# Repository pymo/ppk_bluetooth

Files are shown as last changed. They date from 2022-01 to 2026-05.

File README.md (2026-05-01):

# Palm Portable Keyboard Bluetooth Adapter

This project is a DIY Bluetooth module for the Palm Portable Keyboards (PPK), so you can assemble it to your PPK and use it with any host that supports BLE (Bluetooth 4.0 and later).

Where to buy:

I've made some version 3 adapter for sale. Here is the link to the product: [https://www.tindie.com/products/26595/](https://www.tindie.com/products/26595/)

Demo on Youtube:

Bluetooth Palm Portable Keyboard demo (https://www.youtube.com/watch?v=qPznzD5e45k "Version 3 of my Palm Portable Keyboard Bluetooth Adapter (CH582F based)")

This project is inspired by [cy384](https://github.com/cy384/ppk_usb)'s USB PPK adapter, and [Christian](https://hackaday.io/project/181800-palm-pilot-keyboard-bluetooth-conversion)'s ESP32-based PPK bluetooth adapter. 

I've made 3 versions of the adapter: version 1 is based on an Adafruit Feather nRF52840 Express board, version 2 is based on a LilyGo-T-OI-PLUS ESP32-C3 board. version 3 is based on my custom designed CH582F board. Here are the differences of these versions.

| version | Build Tutorial | Highlights | 
| :---: | :---: | :---: |
| Version 1 | [Tutorial](version1_tutorial.md) | Based on an Adafruit Feather nRF52840 Express board. Experimental, no longer supported. Hard to make. Expensive. Micro USB charging. |
| Version 2 | [Tutorial](version2_tutorial.md) | Based on a LilyGo-T-OI-PLUS ESP32-C3 board. Easy to build, cheap, power hungry, no USB HID support. Type-C charging. no longer supported. |
| Version 3 | [Tutorial](version3_tutorial.md) | Based on my custom designed PCB using CH582F chip. Easier to build, cheap, power efficient, USB HID support. Multi-host support. Type-C charging. |

version 3 is the current one I sell in my online store. If you want to DIY and don't want to buy my board, you can choose version 2. version 1 is really old and no longer supported.

- Supported keyboard types
  - Palm III keyboard (p/n P10713U or 3C10317)
  - Palm V keyboard (p/n 3C10439 or Belkin F8E458)
  - Palm M500 keyboard (p/n P10802U or Belkin F8P3501)
  - Handspring Visor (Targus PA800)
  - HP Jornada (Targus PA820)
  - Sony Clie (Targus PA830)
- Unsupported keyboard types
  - connectors for Treo, other PDA/phones, IrDA version.
  - Compaq iPaq PocketPC (Taugus PA840)

Special Key mapping
-----------
- Fn+Tab for Esc
- Fn+number keys for F1-F10, Fn+- for F11, Fn+= for F12
- Fn+up for volume up, Fn+down for volume down
- Fn+left for brightness down, and Fn+right for brightness up.
- Fn+Cmd is Homepage key (Home button in iOS and Android).
- Cmd is mapped to Windows/Apple key.
- Date is mapped to Home, Phone is mapped to End.
- To-Do is mapped to PageUp, Memo is mapped to PageDown.
- Done is mapped to Insert.

Coverage
-----------
Here are some blog posts covering this project:
- [Palm Portable Keyboard Goes Wireless](https://hackaday.com/2022/02/08/palm-portable-keyboard-goes-wireless/) on Hackaday.
- [Upcycling a Palm Portable Keyboard Into a Bluetooth-Enabled Accessory](https://www.hackster.io/news/upcycling-a-palm-portable-keyboard-into-a-bluetooth-enabled-accessory-9ac6c659c1f3) on hackster.io.
- [A Palm Portable Keyboard Bluetooth Adapter](https://www.hackster.io/news/upcycling-a-palm-portable-keyboard-into-a-bluetooth-enabled-accessory-9ac6c659c1f3) on Adafruit blog.

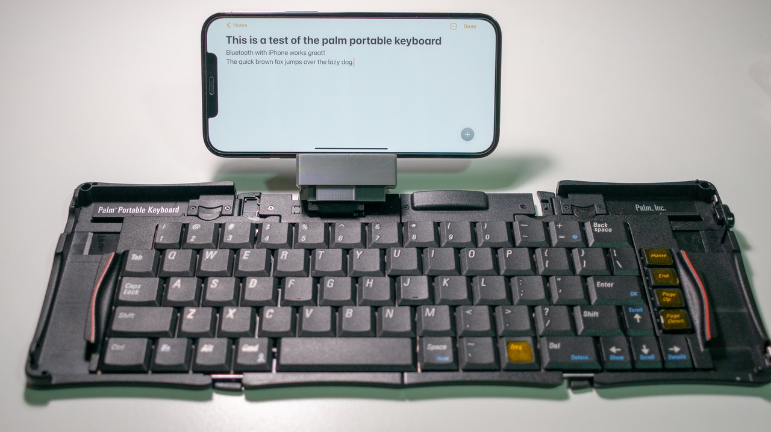
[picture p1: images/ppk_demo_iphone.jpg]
Bluetooth Palm Portable Keyboard's stand supporting an iPhone Bluetooth Palm Portable Keyboard working with a phone


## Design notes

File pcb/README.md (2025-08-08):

# PCB of the version 3 adapter

The version 3 adapter's PCB design and firmware are on [another repository](https://github.com/pymo/wch_micro_kbd), because it is shared with other projects.

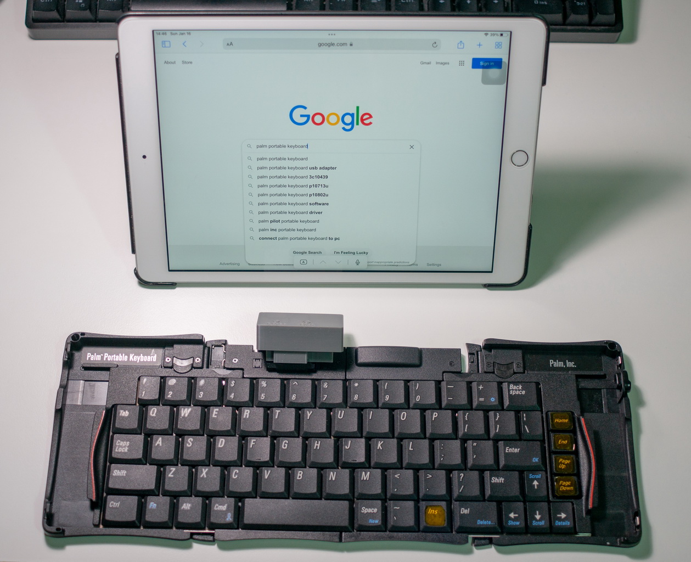
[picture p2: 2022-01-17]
images/ppk_demo.jpg

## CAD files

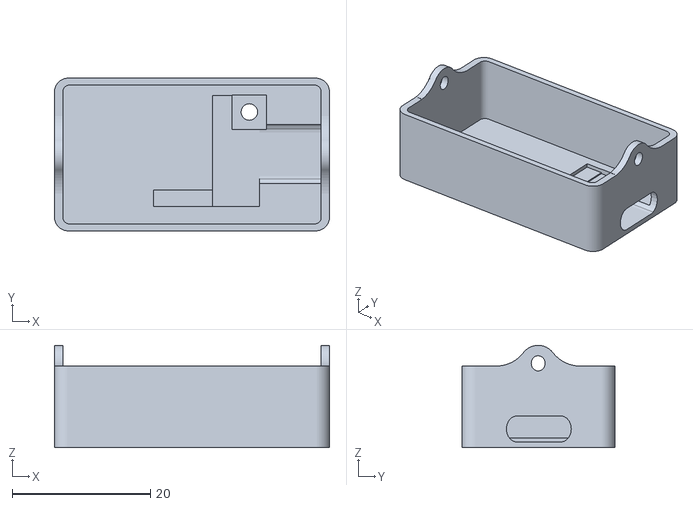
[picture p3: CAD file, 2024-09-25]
3d_print/version3/upper_cap.stl
39.8 x 22.1 x 14.8

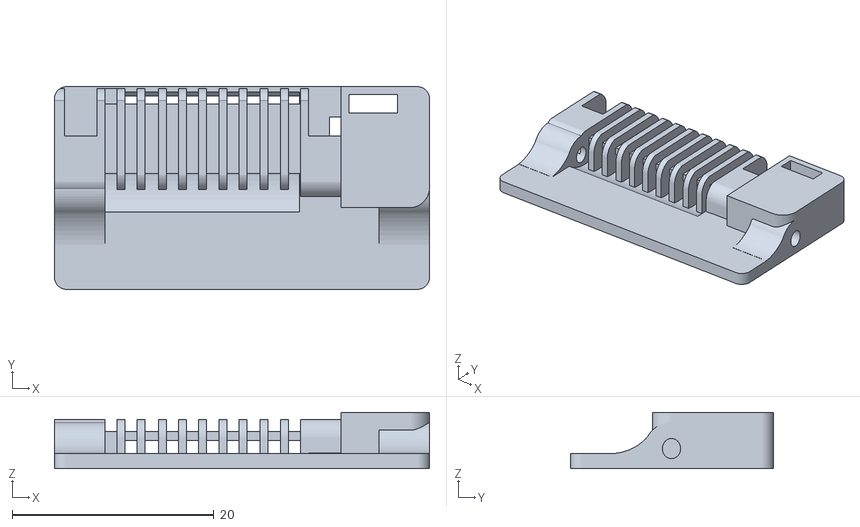
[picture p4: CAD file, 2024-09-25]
3d_print/version3/middle_frame_palm_V.stl
37.2 x 20.1 x 5.60

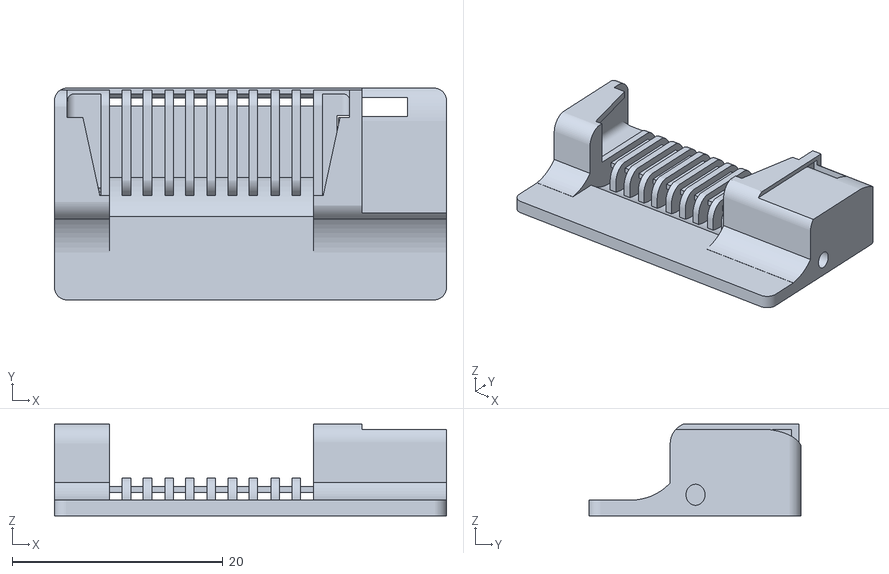
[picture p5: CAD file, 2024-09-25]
3d_print/version3/middle_frame_palm_III.stl
37.2 x 20.1 x 8.70

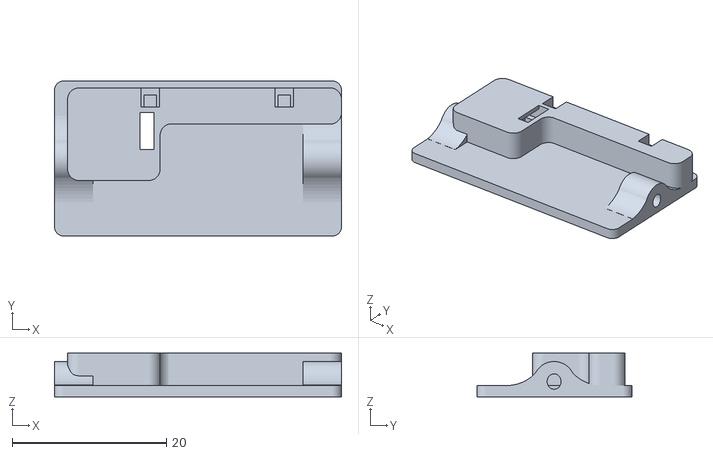
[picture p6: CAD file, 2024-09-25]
3d_print/version3/middle_frame_palm_m500.stl
37.2 x 20.1 x 5.70

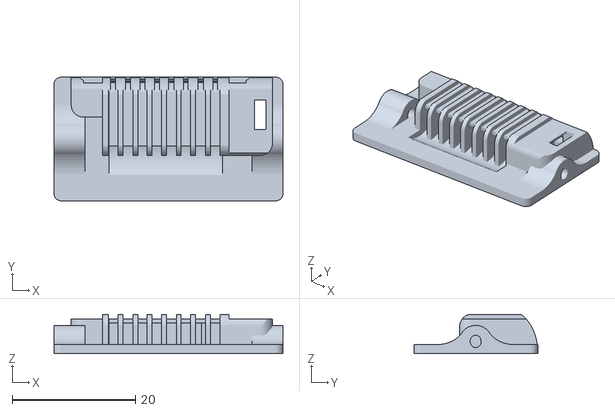
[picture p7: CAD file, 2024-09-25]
3d_print/version3/middle_frame_handspring.stl
37.2 x 20.1 x 6.40

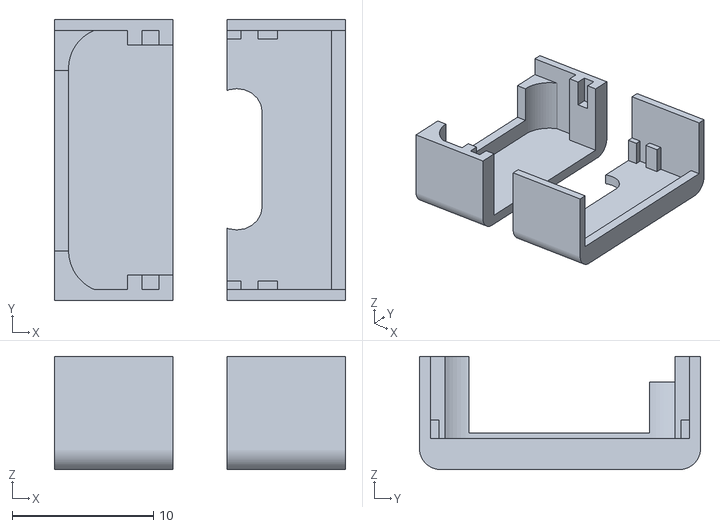
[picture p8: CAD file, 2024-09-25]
3d_print/version3/board_clips.stl
20.6 x 19.9 x 8.00

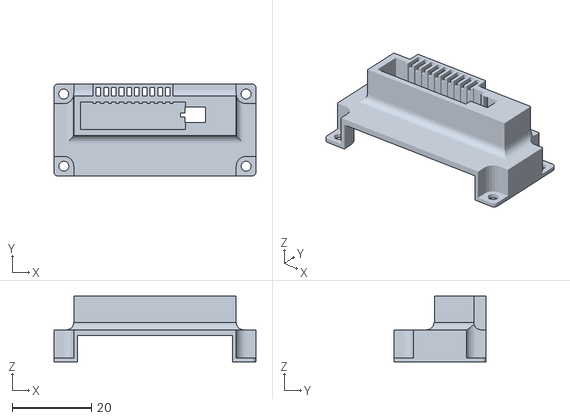
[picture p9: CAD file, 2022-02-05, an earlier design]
3d_print/version1/middle_frame_palm_III.stl
51.1 x 23.3 x 16.6

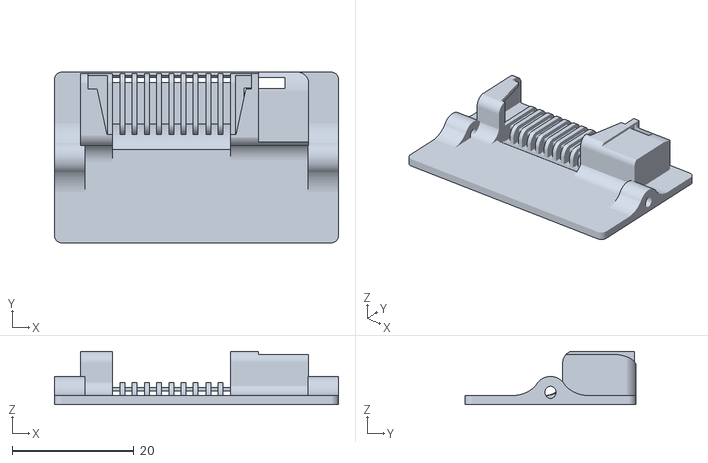
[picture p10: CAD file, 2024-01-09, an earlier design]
3d_print/version2/middle_frame_palm_III.stl
46.6 x 28.0 x 8.70

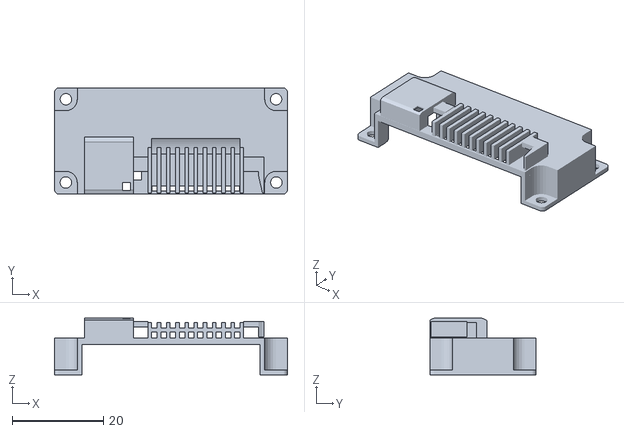
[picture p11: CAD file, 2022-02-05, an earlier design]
3d_print/version1/middle_frame_palm_V.stl
51.1 x 23.3 x 12.4

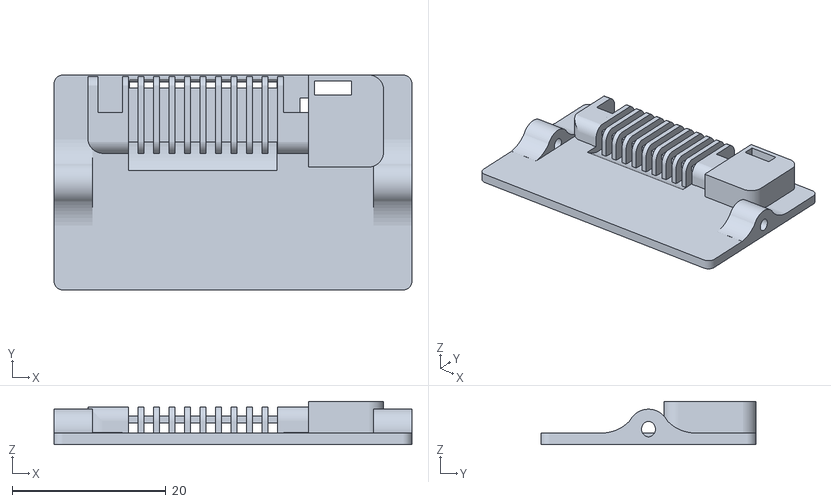
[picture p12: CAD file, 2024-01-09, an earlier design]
3d_print/version2/middle_frame_palm_V.stl
46.6 x 28.0 x 5.60

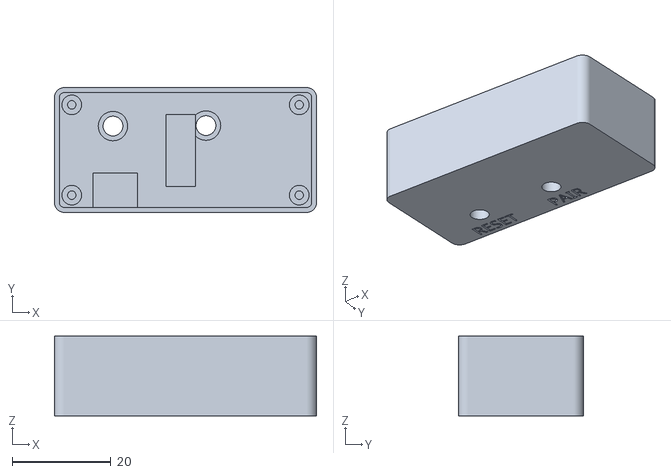
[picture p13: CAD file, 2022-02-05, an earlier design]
3d_print/version1/upper_cap.stl
53.1 x 25.3 x 16.2

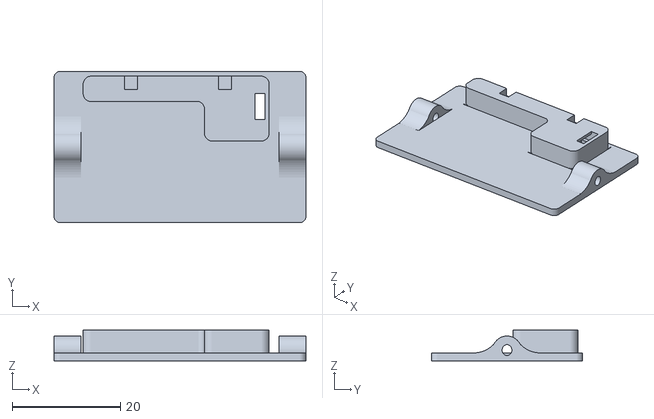
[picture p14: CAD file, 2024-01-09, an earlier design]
3d_print/version2/middle_frame_palm_m500.stl
46.6 x 28.0 x 5.70

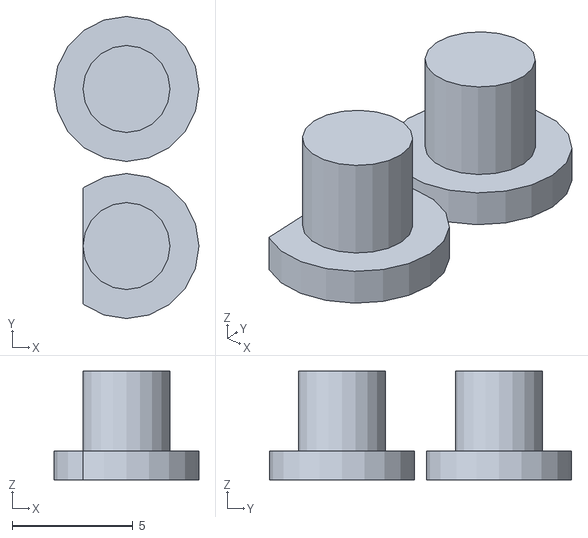
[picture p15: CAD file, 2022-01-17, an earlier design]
3d_print/version1/buttons.stl
6.00 x 12.5 x 4.50

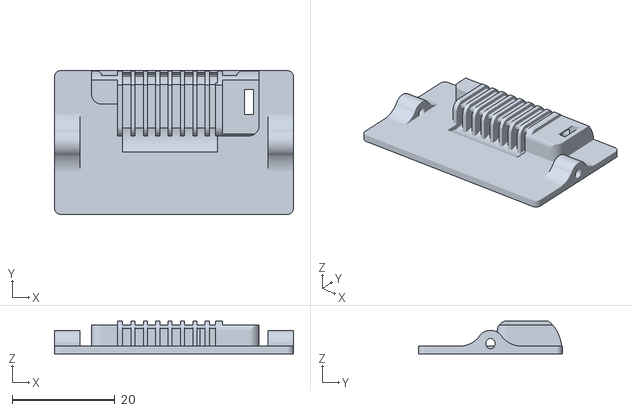
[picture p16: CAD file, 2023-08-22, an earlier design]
3d_print/version2/middle_frame_handspring.stl
46.6 x 28.0 x 6.40

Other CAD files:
3d_print/version2/upper_cap.stl
3d_print/version2/board_clips.stl
3d_print/version2/battery_spacer.stl

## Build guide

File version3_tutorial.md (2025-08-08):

# How to make the version 3 adapter (CH582F based)

If you don't want to make it yourself, you can skip this tutorial and buy the fully assembled adapter at https://www.tindie.com/products/26595/

Bill of Materials
----------
- [WCH Micro Kbd board](https://github.com/pymo/wch_micro_kbd/), you can buy it from my [Tindie store](https://www.tindie.com/products/35183/). You can also fabricate it yourself using the gerber file in [my other repo](https://github.com/pymo/wch_micro_kbd/tree/main/pcb/).
- 22 AWG single core wire for making the connector.
  - or, a [custom interface PCB](https://oshwhub.com/chen_xin_ming/palm-m500-connector) if you are making for Palm M500 keyboards. You can fabricate it yourself, or buy it from my [Tindie store](https://www.tindie.com/products/35183/).
- Some thin, flexible wire for the switch connection. I use 30 AWG PVDF insulated single core wire.
- 601230 Li-Po battery 200mAh (6mm x 12mm x 30mm in dimensions).
- One travel limit switch, model No. [KFC-V-204F or MS-V-204F](https://www.aliexpress.com/item/3256804072080898.html). Please use this exact model, because the enclosure is specifically designed around it.
- 3D printed enclosure (stl models are in the 3d_print/ folder).
- Two M2 screws, 4mm long.
- Double-sided tape, and super glue.

Schematic
----------

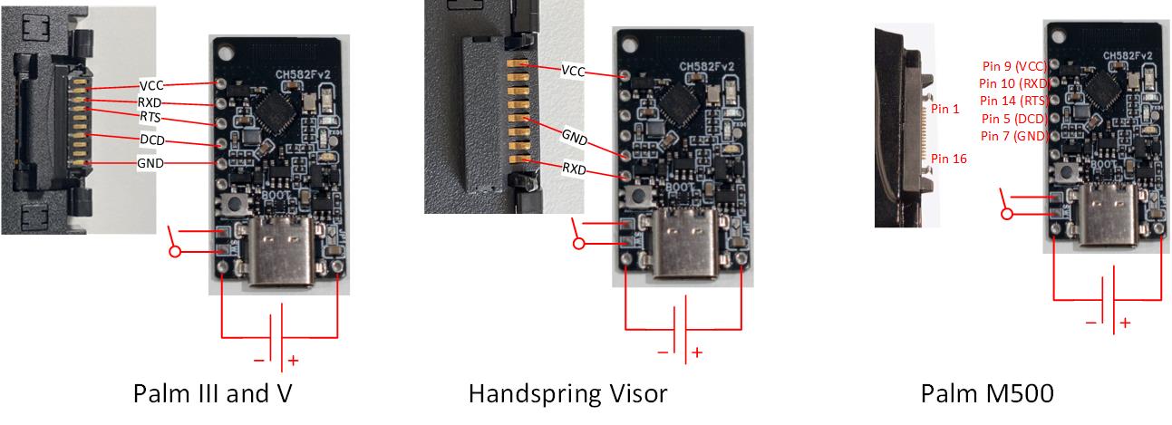
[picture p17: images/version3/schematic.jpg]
Schematic


Some notes about the schematic:

- cy384 explained the keyboard's pinout and protocol in his [project page](http://www.cy384.com/projects/palm-keyboard.html) very well. And here is the official [Hardware and Electronics Reference](http://www.splorp.com/pdf/stowawayhwref.pdf) for the keyboard.

3D printed parts
----------------
See the stl files in 3d_print/ folder. It comes in 3 files: the upper cap, the middle frame and two board clips. The board clips need to be super-glued to the middle frame during the assembly.

I used Tinkercad to create these models. If you are interested in modifying the 3D models, you can visit this link: https://www.tinkercad.com/things/hjglHkgPCuu

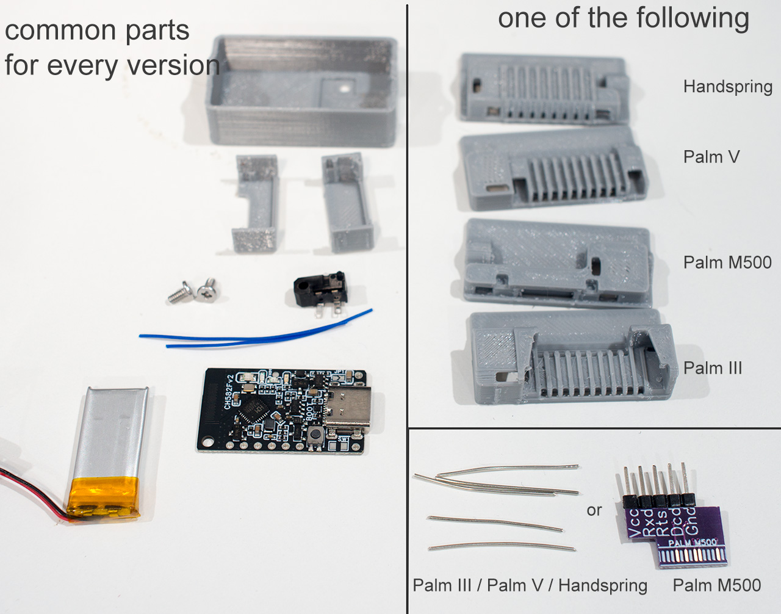
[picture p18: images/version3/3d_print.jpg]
Printed parts before assembly


Assembly and wiring
-------------------

Solder two 4 cm lenth thin wires to the SW1 pads, and the other ends of wires to the travel limit switch.

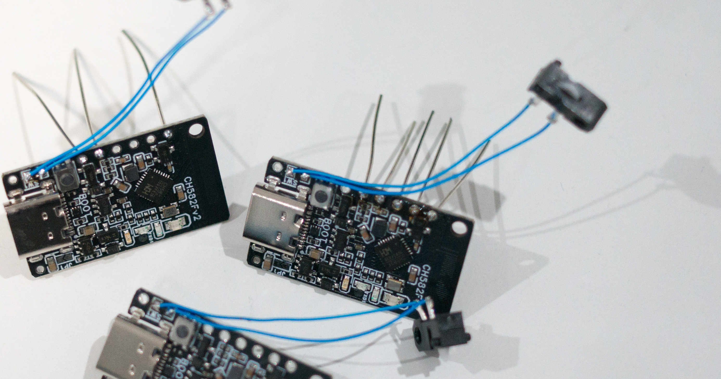
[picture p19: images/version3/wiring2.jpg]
wiring pic


If you are making adapters for Palm III or V, or Handspring Visor:

- Cut the single core wire into five (for Palm III or V) or three (for Handspring Visor) 3.2 cm sections, leave 5mm of the insulation on them.

  - Palm III or V: solder the wires to pin [1] [2] [3] [4] [5].

  - Handspring Visor: solder the wires to pin [1] [5] [6].

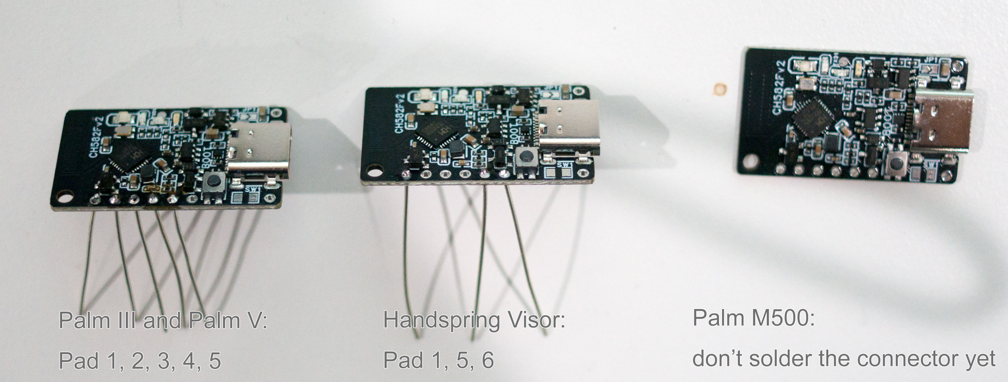
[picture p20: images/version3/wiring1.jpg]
wiring pic


If you are making adapters for Palm M500:

- Use a 5 pin header, solder them to the custom PCB, remove the plastic from the pin header, trim them to 2mm long, put Kapton or electrical tape on the solder joints to insulate.

If you are making adapters for HP Jornada:

- Use a L-shape 5 pin header, trim it and solder it to the custom PCB, put electrical tape on the solder joints to insulate.

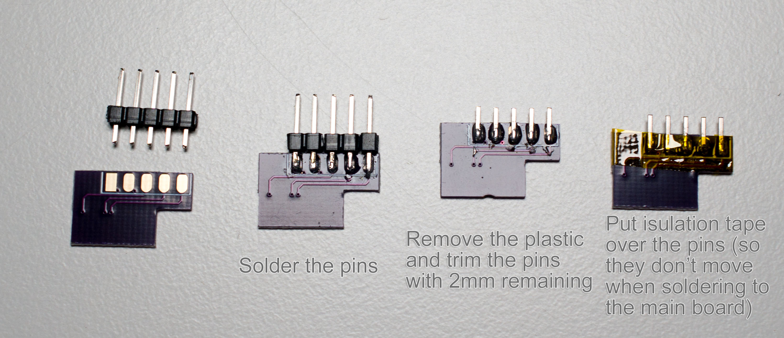
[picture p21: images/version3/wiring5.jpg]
wiring for Palm M500 keyboards


Solder the positive of the Li-Po battery to pad [BAT+], the negative to pad [BAT-].

Use a double-sided tape to glue the battery spacer to the back side of the board, then use a double-sided tape to glue the battery to the battery spacer.

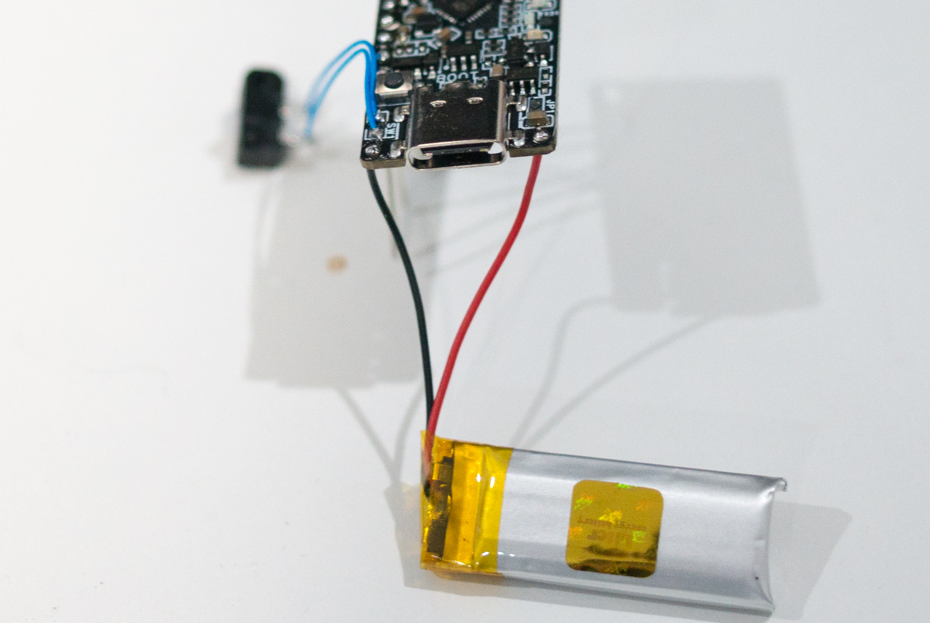
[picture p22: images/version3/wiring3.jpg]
wiring pic


Put some super glue and install the switch inside the middle frame, glue it in-place.

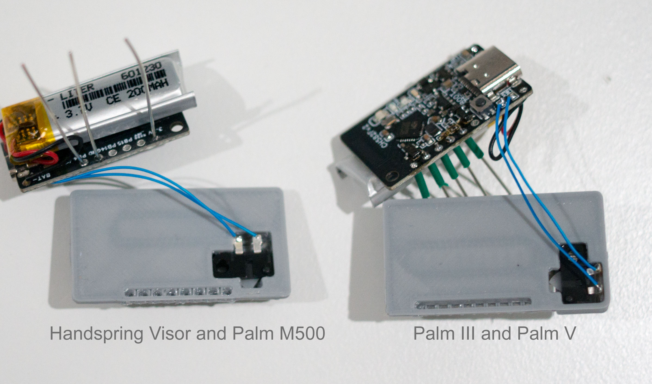
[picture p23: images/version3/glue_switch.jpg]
Glue the switch


Insert the wires into the holes of the middle frame, make sure you are inserting them into the correct hole by cross-check with the schematic.

- Palm III or V: from left to right, pin [1] [2] [3] [4] [5] goes to hole 2, 3, 4, 7, 10

- Handspring: from left to right, pin [1] [5] [6] goes to hole 1, 5, 8

- Palm M500: plug the connector PCB into the middle frame, then put the mainboard & battery assembly on the middle frame, the pins should go through the corresponding pads on main board. Do not solder the pins to the mainboard yet.

- HP Jornada: screw the connector PCB into the middle frame, then put the mainboard & battery assembly on the middle frame, the pins should go through the corresponding pads on main board. Do not solder the pins to the mainboard yet.

Glue the two board clips to the middle frame, the board clips hold the board like this:

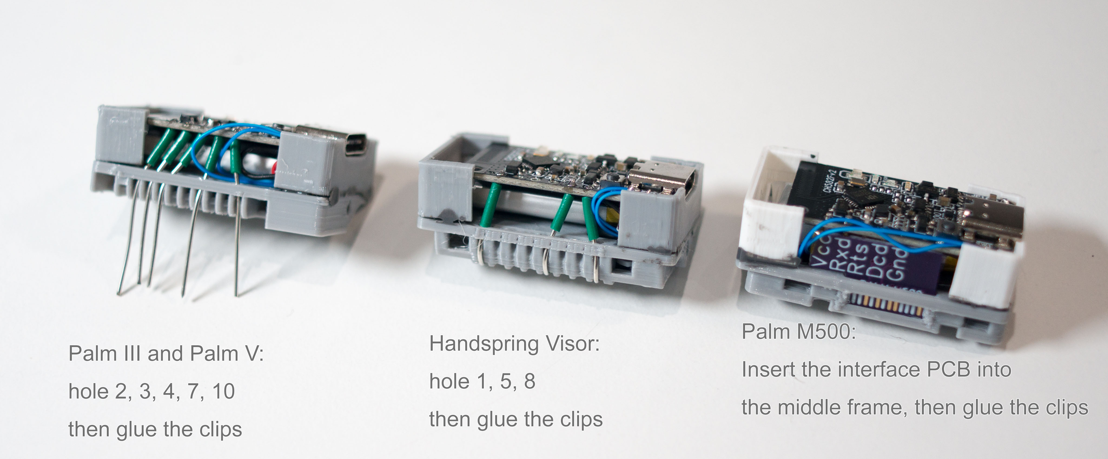
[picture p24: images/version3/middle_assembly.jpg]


- Palm III, V or Handspring: Trim the wires to suitable length, then bend the wires and fold them inside. This is what contacts the keyboard connector.

- Palm M500 or HP Jornada: solder the pins to the mainboard.

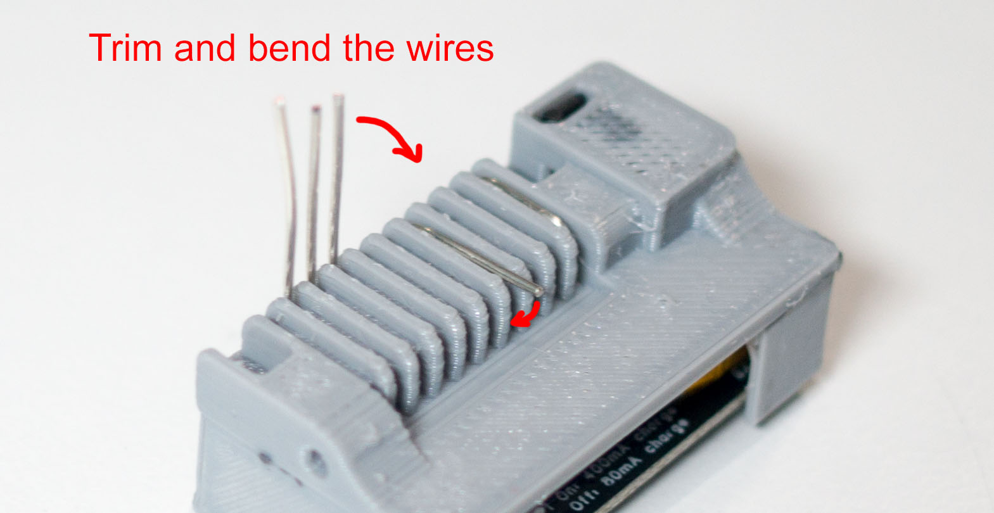
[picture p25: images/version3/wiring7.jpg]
wiring pic


Put the cap over the middle frame. Make sure it is the correct orientation (the USB type-C port should align with the opening on the cap).

Screw the 2 screws, and you are done!

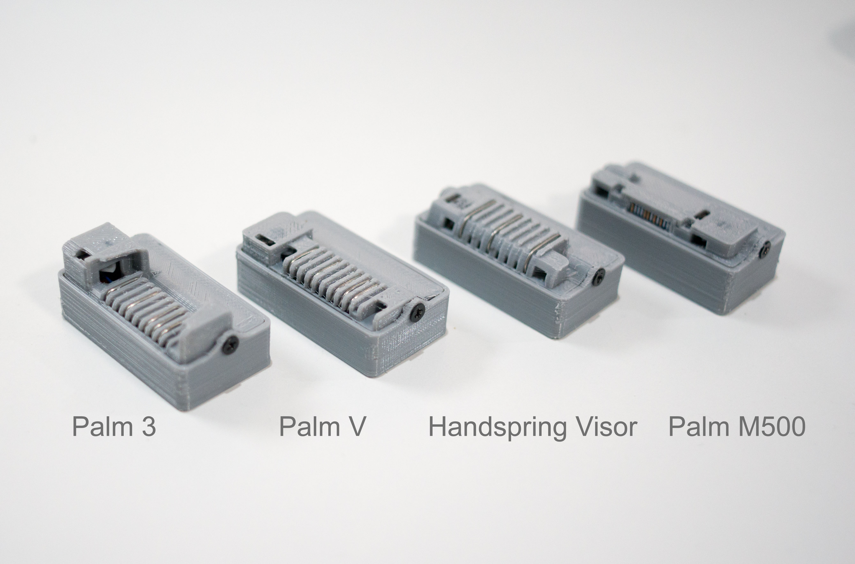
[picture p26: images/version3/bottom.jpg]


Programming
-----------
Follow [this tutorial](https://github.com/pymo/wch_micro_kbd/blob/main/doc/wch_isp_tool.md) to flash the firmware. The firmware can be downloaded from the release page of that github. You need Windows PC to flash the firmware.

Features and quirks
---------------------
- As with any device using Li-Po battery, don't discharge the battery to a very low state. Please charge the battery as soon as you see the red LED blinks. Otherwise the battery health may be affected.

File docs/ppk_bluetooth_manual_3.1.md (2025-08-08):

# Palm Portable Keyboard Bluetooth Adapter Manual

hardware rev. 3.1 2024-09-15

How to use:
  * Plug the adapter into the Palm Portable Keyboard, it automatically powers on. Search it on your 
    phone or PC's Bluetooth settings, it shows up as "PDA Keyboard 1". Pair it and it will work.
  * The adapter supports pairing up to 4 Bluetooth hosts simultaneously, and supports wired USB
    connection, too.
      * Press Fn+A, S, D or F to switch between Bluetooth hosts 1~4, the Bluetooth name is
        "PDA Keyboard 1/2/3/4", respectively.
      * Long press Fn+A, S, D or F for 1 second to force that "channel" into pairing mode
        again.
      * Press Fn+U to switch to USB mode (it does not automatically switch to USB mode
        when USB cable is plugged in, the user has to manually switch it)
  * To factory reset the adapter, use a pin or a paper clip to press and hold the small button on the
    adapter for 3 seconds. Do this if you have pairing issues. You also need to "forget" the keyboard
    in the host's settings before pairing again.
  * The adapter enters sleep mode after idling for 25 minutes. Press any key to wake it up.

LED Functionality:
  * Blue + Green + Red LED constant on: The adapter is handshaking with the keyboard.
      * If it is stuck at this state for more than 3 seconds, it means the adapter is not
        communicating correctly with the keyboard. Please consider the following possibilities:
          * The adapter is not seated properly, please re-attach the adapter, and check if the
            contacts are connected properly.
          * The keyboard may be broken and not responding to the handshake.
          * The adapter may be low on battery, try to charge it for a few minutes.
  * Yellow LED: charging indicator
      * On: charging.
      * Off: charge complete.
  * Blue LED: Bluetooth indicator
      * Blue and Red alternately blink: Bluetooth pairing mode.
      * Fast blink: reconnecting to the last paired host.
      * Slow blink 1/2/3/4 times: Paired to the host 1/2/3/4, normal usage. The blink will stop
        after 1 minute to avoid distraction.
      * Off: USB mode, or the keyboard is in sleep, or it has been more than 1 minute since the
        last Bluetooth host switch.
  * Green LED: Caps Lock indicator
      * On: Caps Lock on.
      * Off: Caps Lock off.
  * Red LED: battery indicator
      * blink once: battery is below 20%.
      * blink twice: battery is below 15%.
      * blink three times: battery is below 10%.

Special Key mapping:

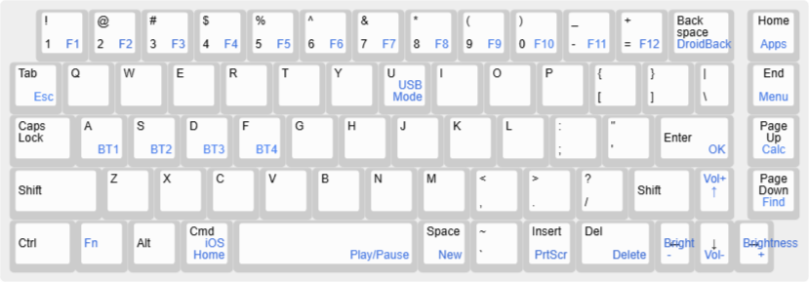
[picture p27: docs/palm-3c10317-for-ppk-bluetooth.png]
palm 3c10317 with ppk bluetooth key mappings


  * Fn+A/S/D/F= Bluetooth host switch
  * Long press Fn+A/S/D/F= pairing mode
  * Fn+U=USB mode

  * Fn+Tab=Esc

  * Fn+1=F1, Fn+2=F2,...,Fn+'='=F12

  * Fn+Cmd=iOS Home
  * Fn+Backspace=Android Back
  * Fn+Space=Play/Pause
  * Fn+<=Previous Song
  * Fn+>=Next Song

  * Done=Insert
  * Fn+Done=PrtScr

  * Fn+Up/Down=Volume Up/Down
  * Fn+Right/Left=Brightness Up/Down

  * Home
  * End
  * Pg Up
  * Pg Down

Notes and Warnings:

This device contains a Lithium-Polymer battery.
  * Please do not crush, disassemble or puncture the device; or short the exposed metal pins. There
    is a risk of fire by doing so.
  * Please recharge as soon as the Yellow LED starts blinking, to maintain the longevity of the 
    battery.
  * If this device is not used for a long time, please charge it at least every 3 months.

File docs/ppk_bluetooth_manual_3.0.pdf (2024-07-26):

# Palm Portable Keyboard Bluetooth Adapter Manual

hardware rev. 3.0 2024-07-25 How to use:
- Plug the adapter into the Palm Portable Keyboard, it automatically powers on. Search it on your phone or PC’s Bluetooth settings, it should show up as “PDA Keyboard 1”. Pair it and it will work.
- The adapter supports pairing up to 4 Bluetooth hosts simultaneously, and supports wired USB connection, too.
- Press Fn+A, S, D or F to switch between Bluetooth hosts 1~4, the Bluetooth name is "PDA Keyboard 1/2/3/4", respectively.
- Long press Fn+A, S, D or F for 1 second to force that "channel" into pairing mode again.
- Press Fn+U to switch to USB mode (it does not automatically switch to USB mode when USB cable is plugged in, the user has to manually switch it)
- To factory reset the adapter, use a pin or a paper clip to press and hold the small button on the adapter for 3 seconds. Do this if you have pairing issues. You also need to "forget" the keyboard in the host's settings before pairing again.
- If the keyboard is idle for 25 minutes, the adapter will enter sleep mode. Press any key to wake it up.

LED Functionality:
- Blue + Green + Yellow LED constant on: The adapter is handshaking with the keyboard.
- If it is stuck at this state for more than 3 seconds, it means the adapter is not communicating correctly with the keyboard. Please consider the following possibilities: ■ The adapter is not seated properly, please re-attach the adapter, and check if the contacts are connected properly.
■ The keyboard may be broken and not responding to the handshake.
■ The adapter may be low on battery, try to charge it for a few minutes.
- Red LED: charging indicator
- On: charging.
- Off: charge complete.
- Blue LED: Bluetooth indicator
- Blue and Yellow alternately blink: Bluetooth pairing mode.
- Fast blink: reconnecting to the last paired host.
- Slow blink 1/2/3/4 times: Paired to the host 1/2/3/4, normal usage.
- Off: USB mode, or the keyboard is in sleep.
- Green LED: Caps Lock indicator
- On: Caps Lock on.
- Off: Caps Lock off.
- Yellow LED: battery indicator
- blink once: battery is below 20%.

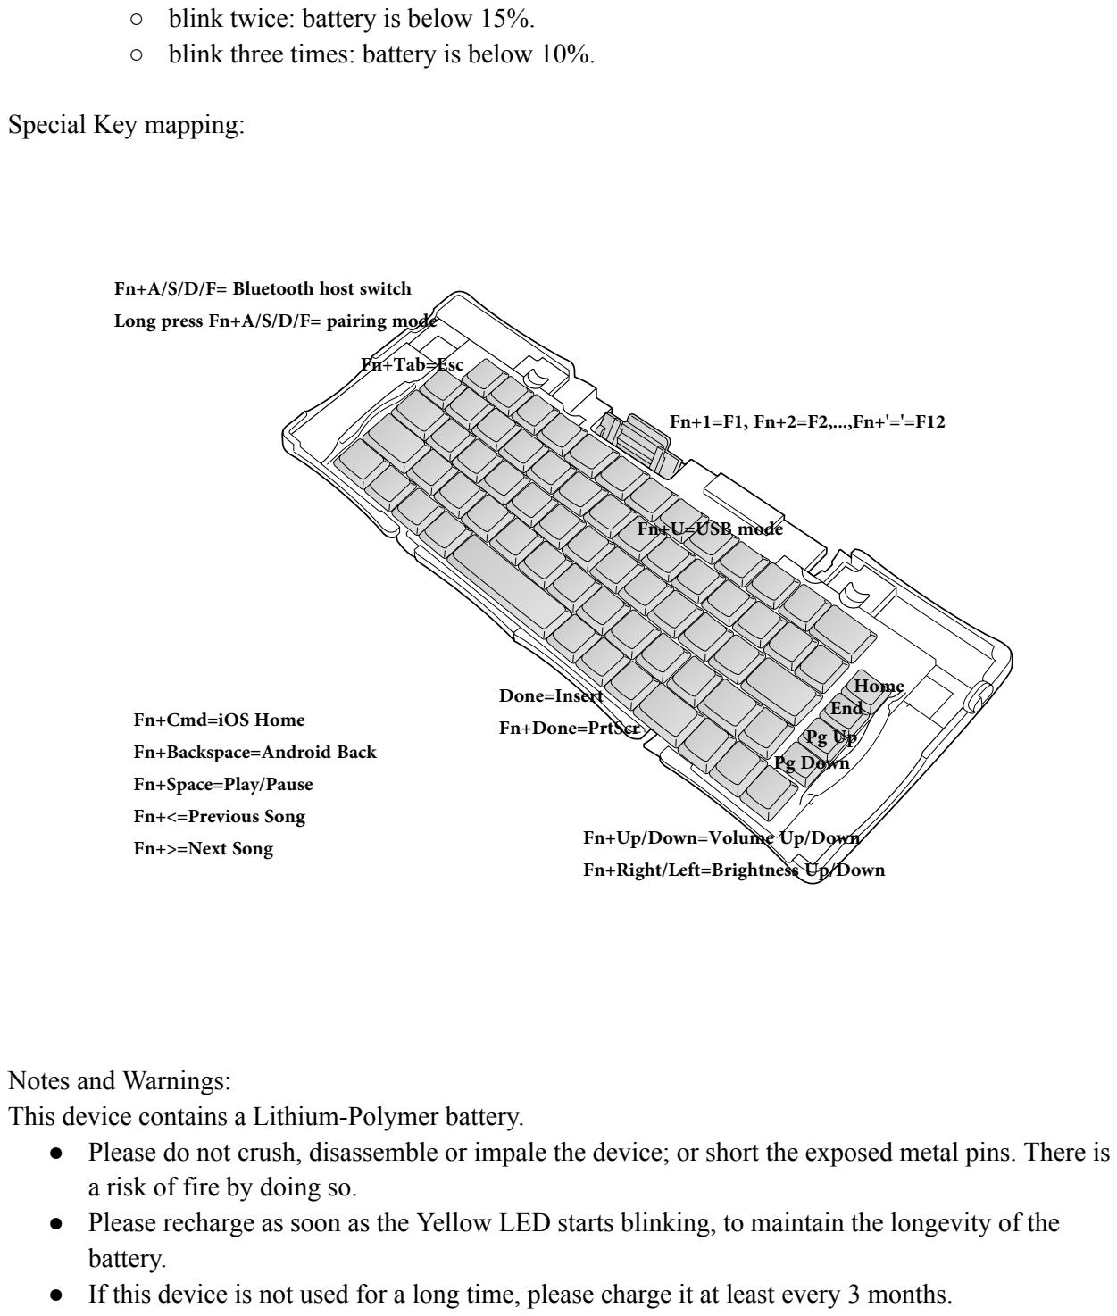
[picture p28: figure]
○ blink twice: battery is below 15%.; Special Key mapping:; Notes and Warnings:; a risk of fire by doing so.; battery.; Home End Pg Up Pg Down; Done=Insert Fn+Done=PrtScr; Fn+Up/Down=Volume Up/Down Fn+Right/Left=Brightness Up/Down; Fn+Tab=Esc; Fn+Cmd=iOS Home Fn+Backspace=Android Back Fn+Space=Play/Pause Fn+<=Previous Song Fn+>=Next Song; Fn+A/S/D/F= Bluetooth host switch Long press Fn+A/S/D/F= pairing mode; Fn+U=USB mode

- blink three times: battery is below 10%.

This device contains a Lithium-Polymer battery.
- Please do not crush, disassemble or impale the device; or short the exposed metal pins. There is
- Please recharge as soon as the Yellow LED starts blinking, to maintain the longevity of the
- If this device is not used for a long time, please charge it at least every 3 months.

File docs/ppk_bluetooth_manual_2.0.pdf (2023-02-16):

## Palm Portable Keyboard Bluetooth Adapter Manual

hardware rev. 2.0 2022-06-10

This product is a DIY Bluetooth adapter for the Palm Portable Keyboards (PPK), so you can use it with any phone, tablet or laptop that has Bluetooth 4.0 or later.

How to use:
Plug the adapter onto the Palm Portable Keyboard, it automatically powers on. Search it on your phone or PC’s Bluetooth settings, it should show up as “Palm Keyboard”. Pair it and it will work.
If the keyboard is idle for 30 minutes, the adapter will enter sleep mode. Press any key to wake it up.

LED Functionality:
- Green + Red LED constant on: The adapter is handshaking with the keyboard.
■ | If it is stuck at this state for more than 3 seconds, it means the adapter is not communicating
| correctly with the keyboard. Please consider the following possibilities: The adapter is not seated properly, please re-seat the adapter, or check the contacts visually.
| The keyboard may be broken and not responding to the handshake.
| The adapter may be low on battery, try to charge it for a while.
- Green LED fast flashing: Bluetooth pairing mode.
- Green LED slow flashing: Paired to the host device, normal usage.
- Blue LED on: charging.
- Blue LED off: charge complete.
- Red LED one flash: battery is below 20%.
- Red LED dual flash: battery is below 15%.
- Red LED triple flash: battery is below 10%.
■ (Please recharge as soon as Red LED starts flashing, to maintain the health of the battery.)

Special Key mapping:

# Home End Pg Up Pg Down

# Insert

# Fn+Up/Down=Volume Up/Down Fn+Right/Left=Brightness Up/Down

# Fn+1=F1, Fn+2=F2,...,Fn+'='=F12

# Fn+Tab=Esc

# Fn+Cmd=iOS Home

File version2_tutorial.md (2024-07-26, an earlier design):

# How to make the version 2 adapter (ESP32-C3 based)

Bill of Materials
----------
- [LilyGo TTGO T-OI PLUS ESP32-C3](https://www.aliexpress.us/item/3256803162622213.html) board (no battery holder version, $5.98+shipping)
- 22 AWG single core wire for making the connector.
  - or, a [custom interface PCB](https://oshwhub.com/chen_xin_ming/palm-m500-connector) if you are making for Palm M500 keyboards. You can fabricate it yourself, or buy it from my [Tindie store](https://www.tindie.com/products/35183/).
- Some thin, flexible wire for the switch connection. I use 30 AWG PVDF insulated single core wire.
- 802040 Li-Po battery 700mAh (40mm x 20mm x 8mm in dimensions).
- One travel limit switch, model No. [KFC-V-204F or MS-V-204F](https://www.aliexpress.com/item/3256804072080898.html). Please use this exact model, because the enclosure is specifically designed around it.
- 3D printed enclosure (stl models are in the 3d_print/ folder).
- 2 screws with the length around 5mm and the outer diameter around 2mm. You can also use other size if you are willing to modify the enclosure (The thread density does not matter because it self-taps into the hole)
- Double-sided tape, and super glue.

Schematic
----------
ESP32-C3's hardware serial port has built-in invertion function, and its GPIO has built-in pullup/pulldown, so it does not need any standalone components like the version 1 does.

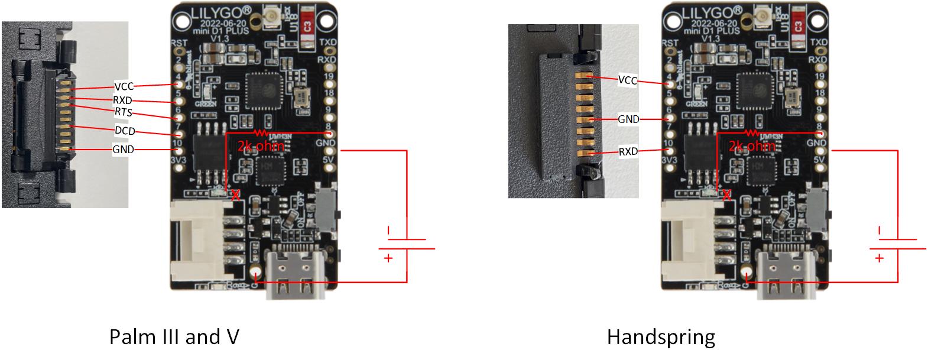
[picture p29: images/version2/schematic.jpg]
Schematic


Some notes about the schematic:

- cy384 explained the keyboard's pinout and protocol in his [project page](http://www.cy384.com/projects/palm-keyboard.html) very well. And here is the official [Hardware and Electronics Reference](http://www.splorp.com/pdf/stowawayhwref.pdf) for the keyboard.
- We directly use GPIO as the "VCC" and "GND" of the keyboard, this way we can easily reboot the keyboard. The keyboard uses less than 2.5mA, so it's OK.
- I used a travel limit switch, and embeded it inside the socket which connects to the keyboard, so that it will be automatically on when the adapter is plugged in.

3D printed parts
----------------
See the stl files in 3d_print/ folder. It comes in 4 files: the upper cap, the middle frame, a battery spacer and two board clips. The board clips need to be super-glued to the middle frame during the assembly. The battery spacer is to prevent the battery to be overheated by the ESP32-C3 chip (just a pre-caution, the board only get slightly warm during normal usage).

I used [Tinkercad](https://www.tinkercad.com/) to create these models. If you are interested in modifying the 3D models, you can visit this link: https://www.tinkercad.com/things/iDDUoFQ8ppK

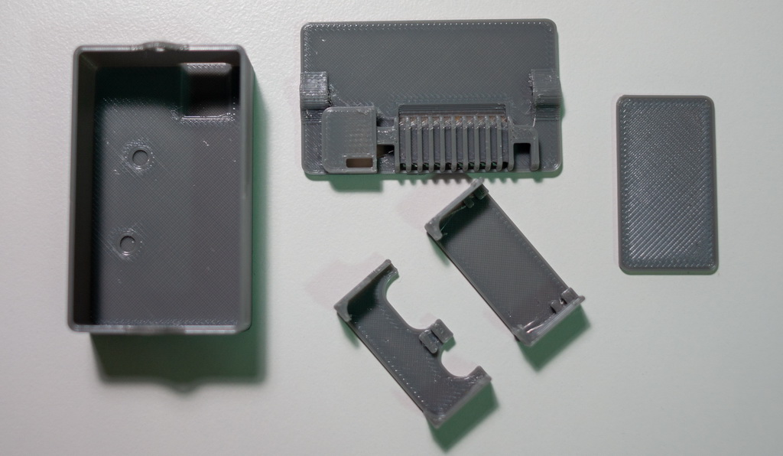
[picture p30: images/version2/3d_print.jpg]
Printed parts before assembly


Assembly and wiring
-------------------

Desolder the 4-pin connector and the power switch.

(optional) Desolder the resistor next to the red LED, solder a 2K ohm resistor between the [8] pad and the positive pin of the red LED. This would re-purpose the red LED to be used by the GPIO8, instead of always on.

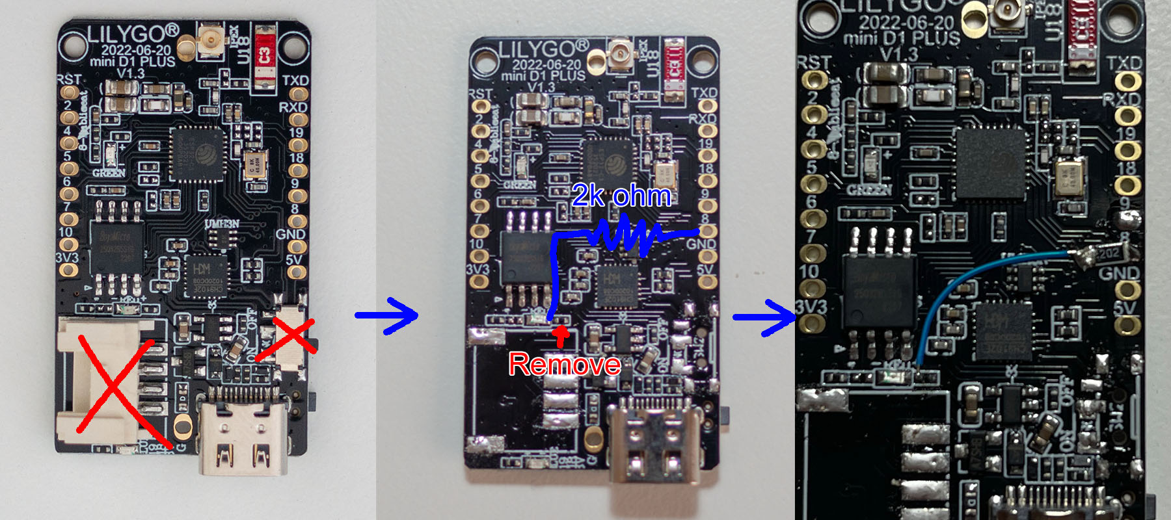
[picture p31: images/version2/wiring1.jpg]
wiring pic


Solder two 5 cm lenth thin wires to the pad where the switch was, and the other ends of wires to the travel limit switch.

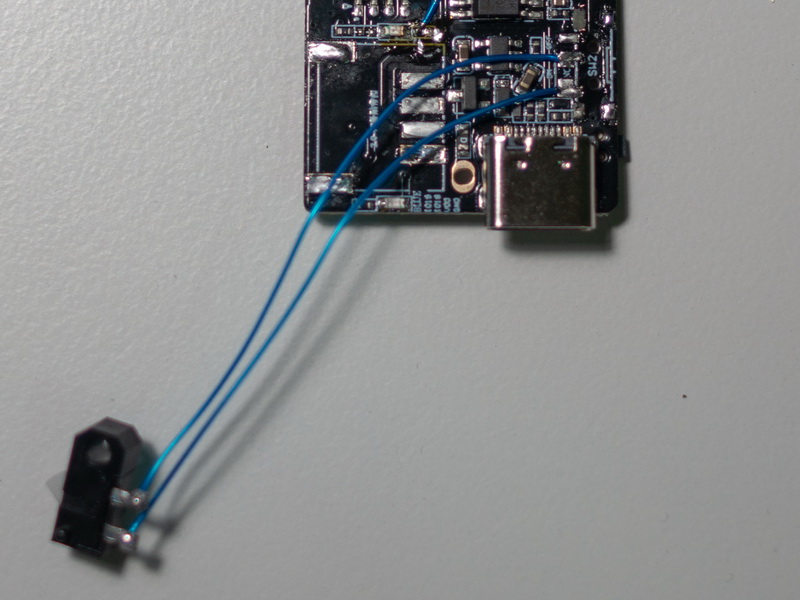
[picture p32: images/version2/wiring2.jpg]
wiring pic


If you are making adapters for Palm III or V, or Handspring Visor:

- Cut the single core wire into five (for Palm III or V) or three (for Handspring Visor) 3.2 cm sections, leave 6mm of the insulation on them.

  - Palm III or V: solder the wires to pin [4] [5] [6] [7] [10].

  - Handspring Visor: solder the wires to pin [4] [6] [10].

If you are making adapters for Palm M500:

- Cut 5 segments of thin wires, solder them to the custom PCB, then solder the wires to pin [4] [5] [6] [7] [10]

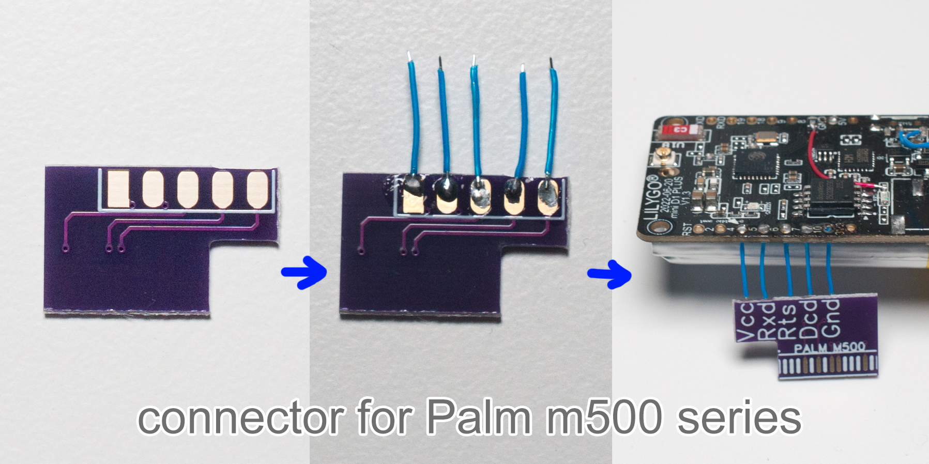
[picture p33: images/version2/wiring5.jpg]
wiring for Palm M500 keyboards


Solder the positive of the Li-Po battery to pad [+], the negative to the [GND] pad.

Use a double-sided tape to glue the battery spacer to the back side of the board, then use a double-sided tape to glue the battery to the battery spacer.

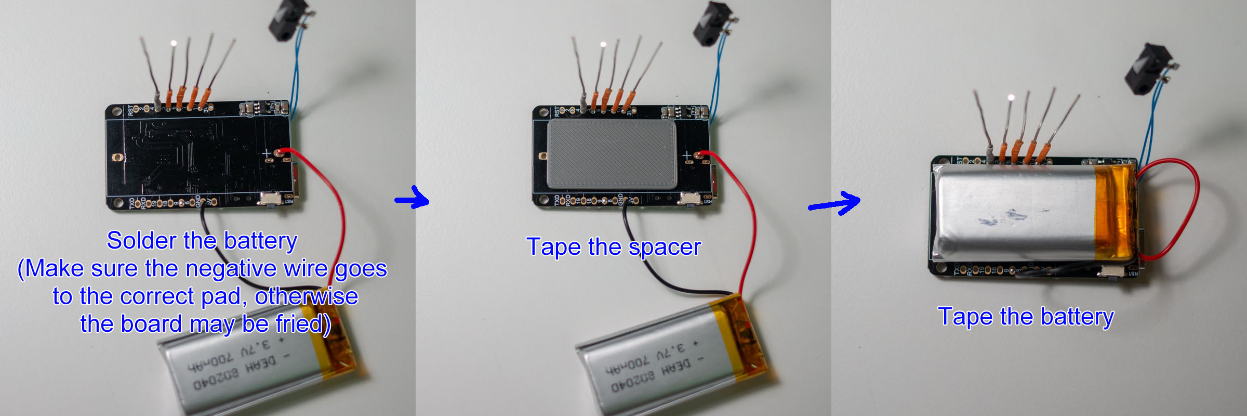
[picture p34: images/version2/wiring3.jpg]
wiring pic


Put some super glue and install the switch inside the middle frame, glue it in-place.

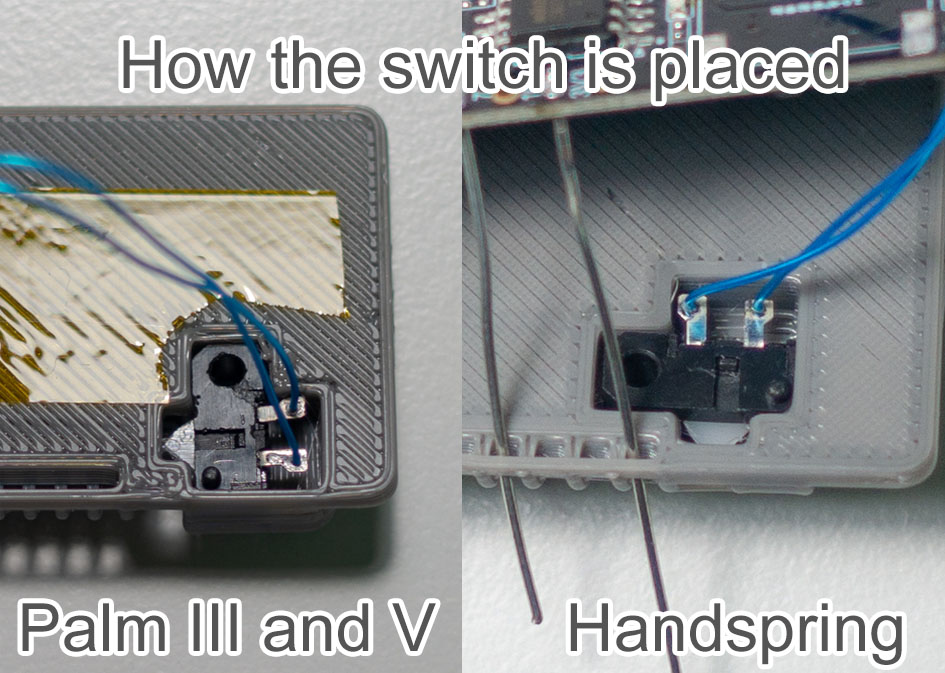
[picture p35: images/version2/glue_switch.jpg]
Glue the switch


Insert the wires into the holes of the middle frame, make sure you are inserting them into the correct hole by cross-check with the schematic.

- Palm III or V: from left to right, pin [4] [5] [6] [7] [10] goes to hole 2, 3, 4, 7, 10

- Handspring: from left to right, pin [4] [6] [10] goes to hole 1, 5, 8

- Palm M500: insert the PCB into the middle frame.

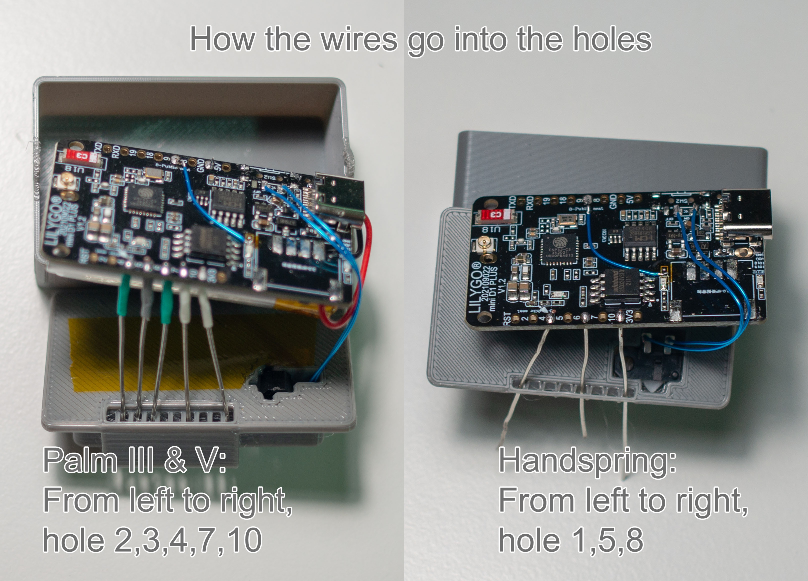
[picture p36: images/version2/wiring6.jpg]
wiring pic


Glue the two board clips to the middle frame, the board clips hold the board like this:

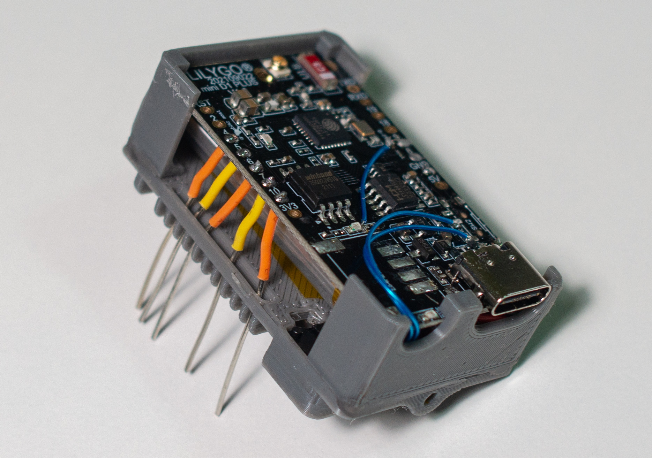
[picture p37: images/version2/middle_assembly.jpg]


Trim the wires to suitable length, then bend the wires and fold them inside. This is what contacts the keyboard connector.

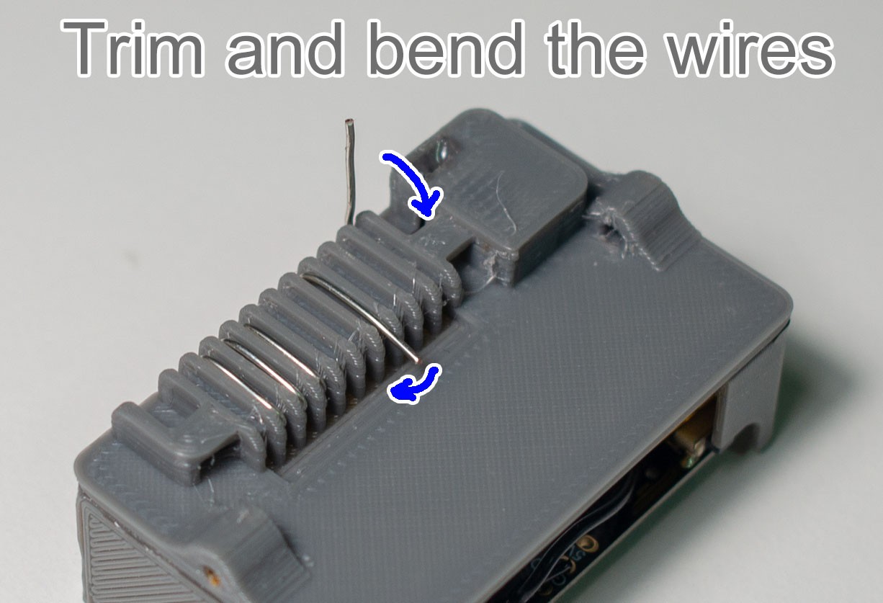
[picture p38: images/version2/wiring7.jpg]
wiring pic


Put the cap over the middle frame. Make sure it is the correct orientation (the USB type-C port should align with the opening on the cap).

Screw the 2 screws, and you are done!

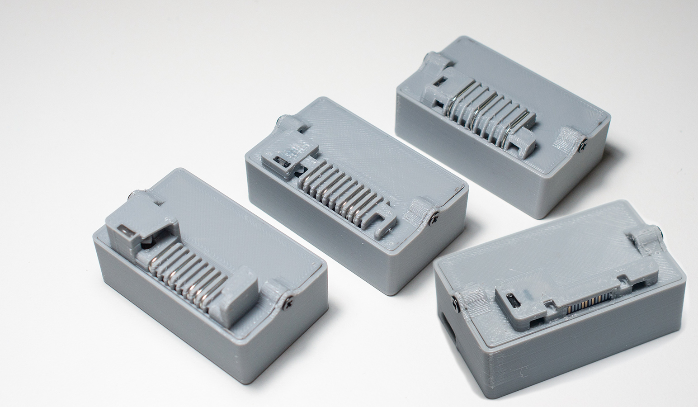
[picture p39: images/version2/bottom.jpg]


Programming
-----------
I find [this tutorial](https://www.electronics-lab.com/getting-started-with-espressifs-esp32-c3-devkitm-1-on-arduino-ide/) very good for teaching how to use the Arduino IDE to program the ESP32-C3 board. Other than the steps in the tutorial, you also need to install the library [NimBLE-Arduino](https://github.com/h2zero/NimBLE-Arduino), refer to the "Installation" section in NimBLE-Arduino's README.

Once you know how to program the board, open up `version2_esp32c3.ino`, plug in the board to the PC using a USB type-C cable, and hit upload, wait for the programming to be done. Then you can test it on the keyboard!

If you are compiling for Handspring Visor keyboard, uncomment the line `#define HANDSPRING` in the file `version2_esp32c3.ino`. If you are compiling for Palm III, V or M500, keep it commented out.

Notes:

- The micro switch needs to be at the "on" position for the board to accept programming, this means you need to plug in the adapter to the keyboard before trying to program.
- Avoid using a USB hub for programming the board, because it may not provide enough current. Use a USB port that is directly on the PC.
- I've heard complaints about this LILYGO T-OI-PLUS's USB-RS232 chip driver is not very stable under macOS. So Windows is preferred.

LED Functionality
---------------------
- Green + Red LED constant on: The adapter is handshaking with the keyboard.
  - If it is stuck at this state for more than 3 seconds, it means the adapter is not communicating correctly with the keyboard. Please consider the following possibilities:
    - The adapter is not seated properly, please re-seat the adapter, or check the contacts visually.
    - The keyboard may be broken and not responding to the handshake.
    - The adapter may be low on battery, try to charge it for a while.
- Green LED fast blink: Bluetooth pairing mode.
- Green LED slow blink: Paired to the host device, normal usage.
- Blue LED on: charging battery.
- Blue LED off: charge complete.
- Red LED one blink: battery is below 20%.
- Red LED dual blink: battery is below 15%.
- Red LED triple blink: battery is below 10%.
  - Please recharge as soon as Red LED starts blinking (<20%), to maintain the battery health.

Features and quirks
---------------------
- It can only connect to one device at a time. It automatically connects to the last device it is paired to (if that device is in range). If you want to connect it to another device, you can manually disconnect it in the last connected device's operating system.
- The board will discharge the battery to a very low state, so please charge the battery as soon as you see the red LED blinks. Otherwise the battery health may be affected.

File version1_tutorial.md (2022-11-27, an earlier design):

# How to make the version 1 adapter (nRF52840-based)

Bill of Materials
----------
- [Adafruit Feather nRF52840 Express](https://www.adafruit.com/product/4062) board ($24.95+shipping)
- About 22 AWG solid core wire for making the connector.
- Some thin, flexible wire for battery and RX connection. I use 30 AWG PVDF insulated solid core wire.
- 502030 Li-Po battery 250mAh (30mm x 20mm x 5mm in dimensions). (The enclosure is specifically designed for this battery size. If you want a larger battery, you may need to modify the enclosure.)
- Three 10K ohm resistors (two SMD 0805 size, one axial)
- One NPN transistor in SMD package (I use 2N3904)
- One switch (I use a tiny travel limit switch, model No. [KFC-V-204F or MS-V-204F](https://www.aliexpress.com/item/3256804245842522.html), you can use any other switch, but you need to modify the enclosure)
- 3D printed enclosure (stl models are in the 3d_print/ folder).
- 4 screws with the length around 5mm and the outer diameter around 2mm. You can also use other size if you are willing to modify the enclosure (The thread density does not matter because it self-taps into the hole)
- super glue.

Schematic
----------
The PPK speaks RS-232 instead of TTL, this means we need to solder some extra components onto the board to make a voltage level inverter.

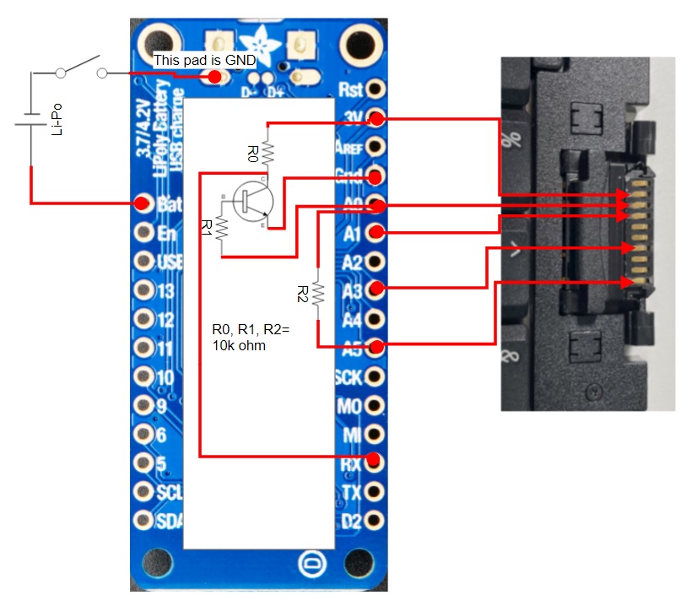
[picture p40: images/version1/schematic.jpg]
Schematic


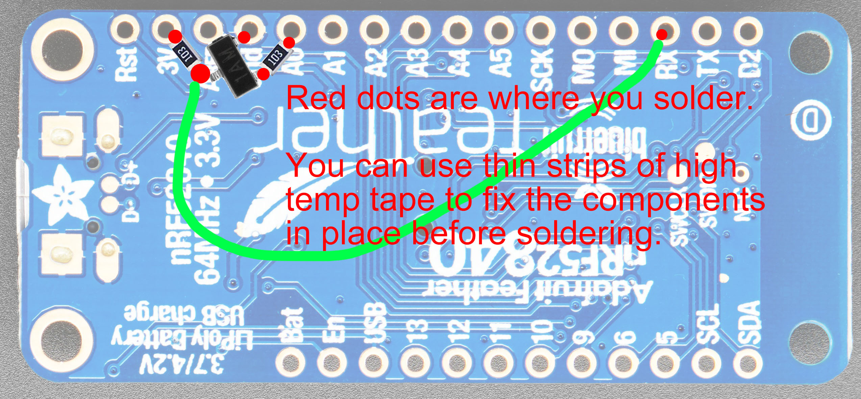
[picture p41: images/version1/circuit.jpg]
Circuit Actual circuit


Some notes about the schematic:

- cy384 explained the keyboard's pinout and protocol in his [project page](http://www.cy384.com/projects/palm-keyboard.html) very well. And here is the official [Hardware and Electronics Reference](http://www.splorp.com/pdf/stowawayhwref.pdf) for the keyboard.
- Red dots are where the wires need to be soldered to the pad.
- Though wires are soldered to pad A0, this GPIO is not used in the software, it is only soldered there to provide structural support of the wire.
- A5 is the "GND" of the keyboard, we could have soldered it to the GND of the board, but then the position would be inconvenient. Instead we pull down A5 in software to act as GND.
- R2 is a pull down resistor for the RTS line, it is required as per the keyboard manual. I chose an axial resistor because its physical length allows it to conveniently "jump" between A0 and A5.
- I used a travel limit switch, because I can embed it inside the socket which connects to the keyboard, so that it will be on automatically when the adapter is plugged in. However, this means the adapter can only be charged when it is plugged to the keyboard. If you don't want this quirky feature, you can use a normal switch and modify the enclosure.

3D printed parts
----------------
See the stl files in 3d_print/ folder. It comes in three parts: the upper cap, the middle frame, and two buttons. The middle frame needs some support under the middle platform when printing.

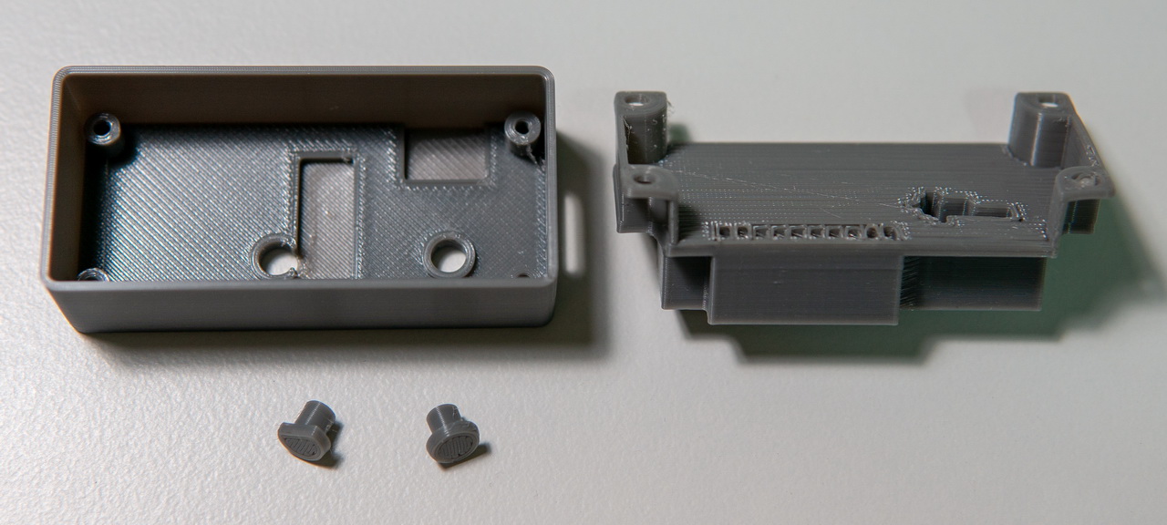
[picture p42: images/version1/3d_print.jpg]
Printed parts before assembly


I used [Tinkercad](https://www.tinkercad.com/) to create these models. If you are interested in modifying the 3D models, you can visit this link: https://www.tinkercad.com/things/cnyYmhGWcyD

Assembly and wiring
-------------------

Cut the single core wire into five 4cm sections, strip the insulation and solder it to pad [3V] [A0] [A1] [A3] [A5], respectively.

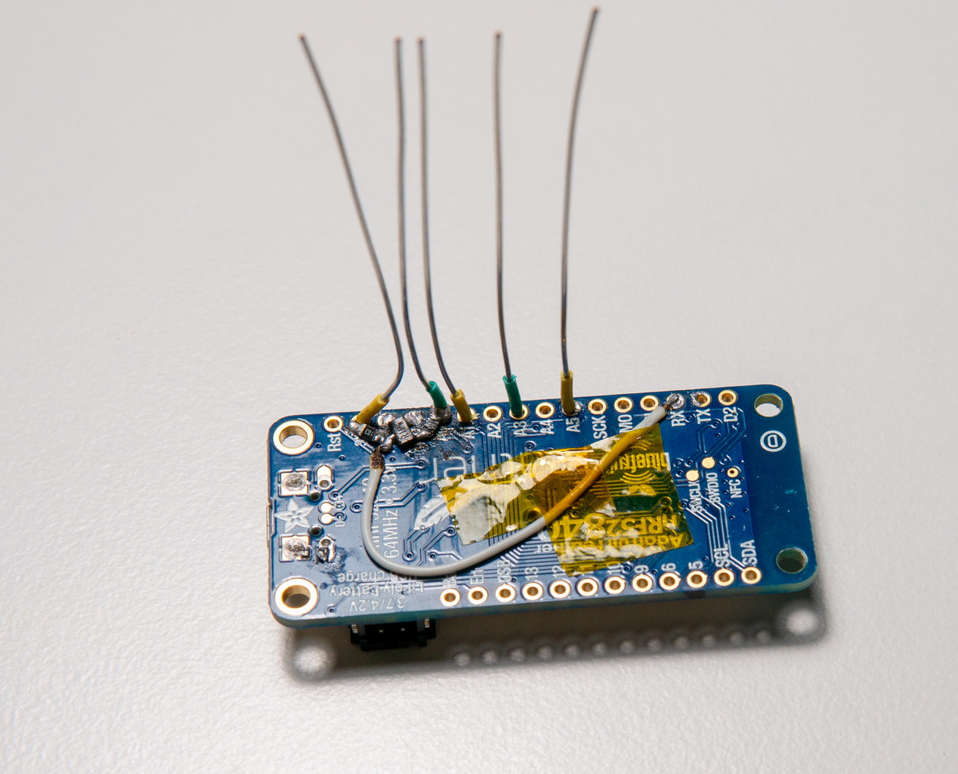
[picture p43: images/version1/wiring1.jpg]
wiring pic


This is the most difficult step: place the transistor and R0, R1 on the board as shown below, and solder them according to the schematic. You have to place the component exactly like I did or it will not reach some pads. You can use thin strips of heat-resistant tape to help fix the components in place when soldering. Double check the connectivity of every junction with multi-meter to make sure there is no short nor disconnect.

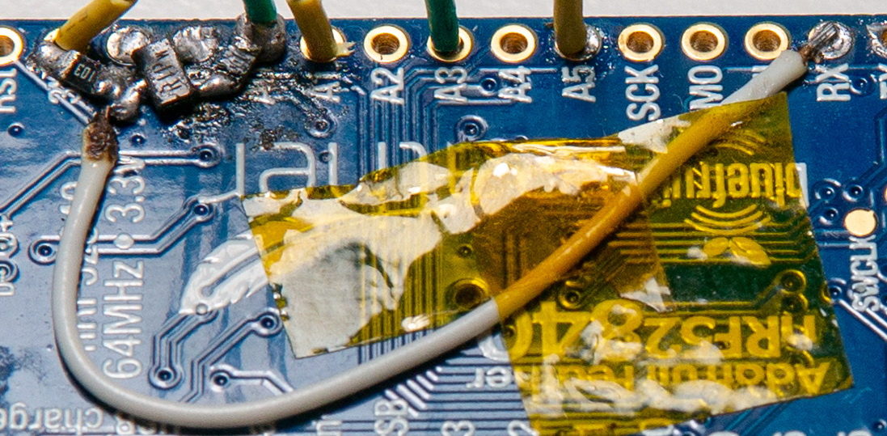
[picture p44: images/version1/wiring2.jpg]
wiring pic


Solder a thin wire from the R0-transistor connection to the [RX] pad.

Solder R2 between [A0] and [A5] on the top of the board. I would recommend putting a heat-shrink tube on the resistor to prevent shorting with the A1 and A3 pin.

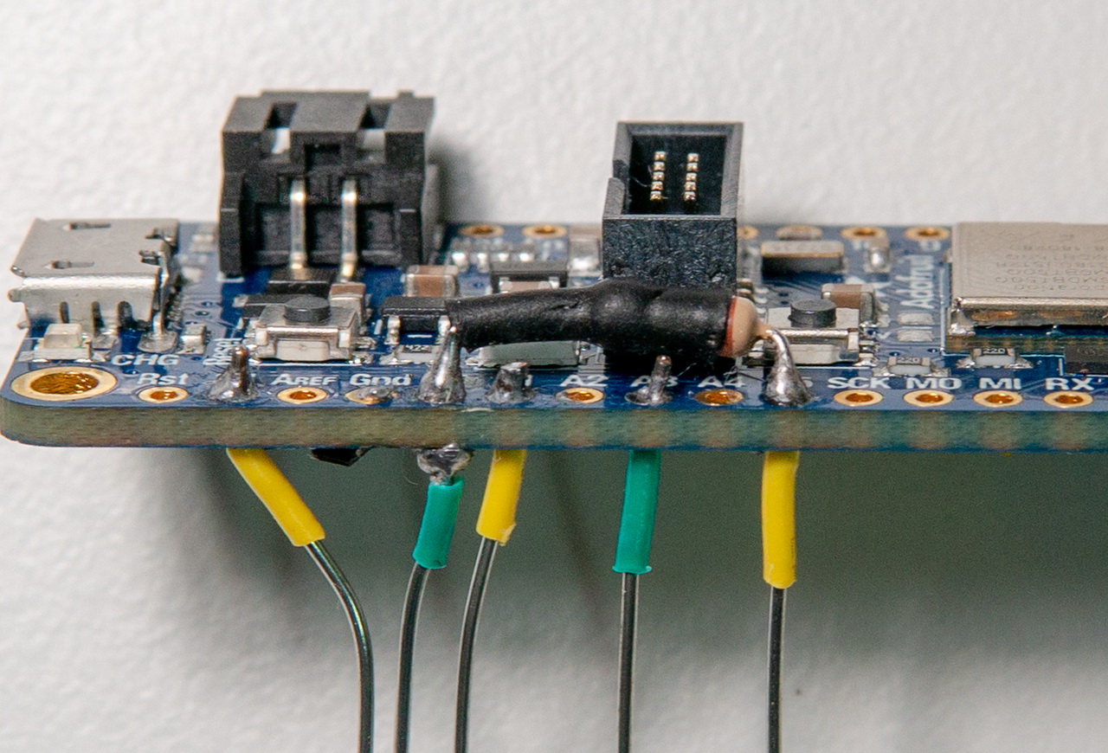
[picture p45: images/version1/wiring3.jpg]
wiring pic


Solder the positive of the Li-Po battery to pad [Bat], the negative to one end of the switch, and the other end of the switch connects to the GND pad of the board as shown in the schematic. Make sure the wires to the switch are at least 5cm long, otherwise it may cause trouble during assembly.

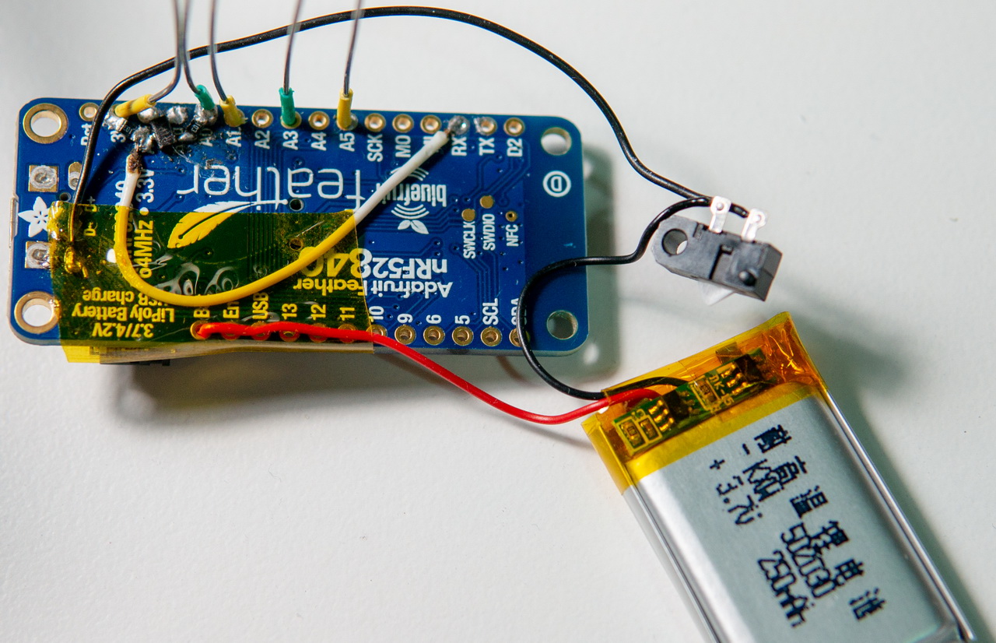
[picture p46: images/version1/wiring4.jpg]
wiring pic


Manage the wire so it is cleanly tucked on the back side of the board. Then use a double-sided tape to glue the battery to the back side of the board.

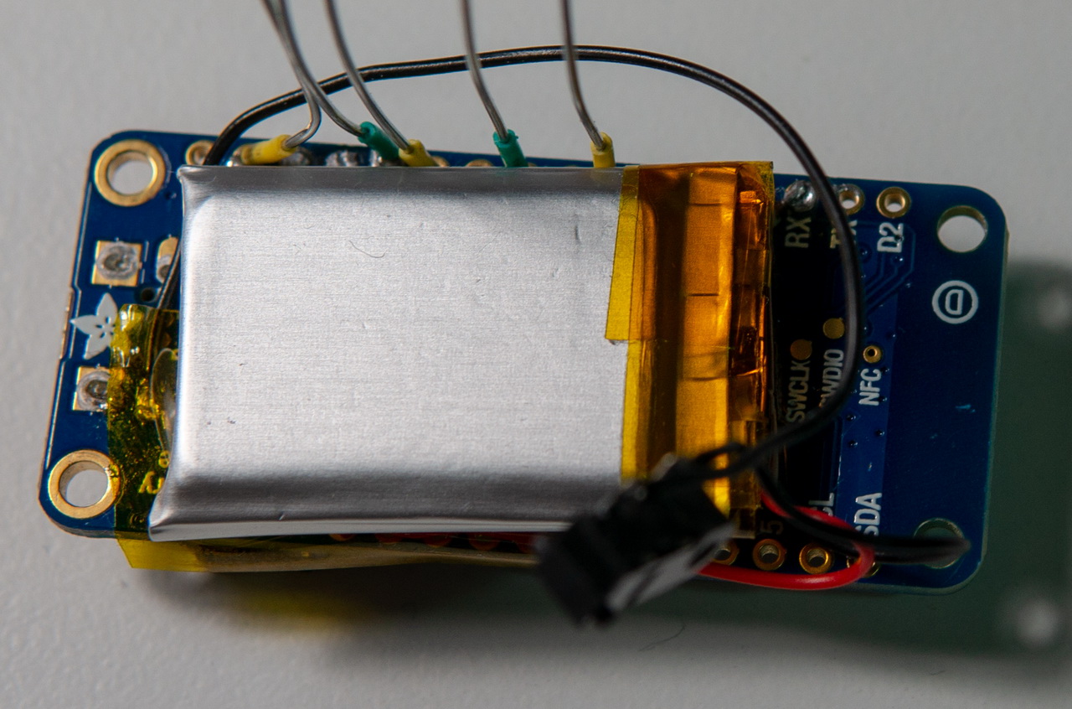
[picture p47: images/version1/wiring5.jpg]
wiring pic


Put some glue and install the switch inside the middle frame, glue it in-place.

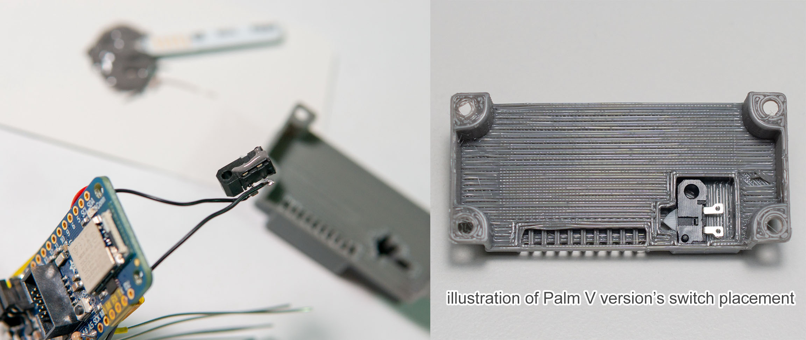
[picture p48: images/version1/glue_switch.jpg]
Glue the switch


Put around 4 mm of insulation on each of the wires, then insert the wires into the holes of the middle frame, make sure you are inserting them into the correct hole by cross-check with the schematic.

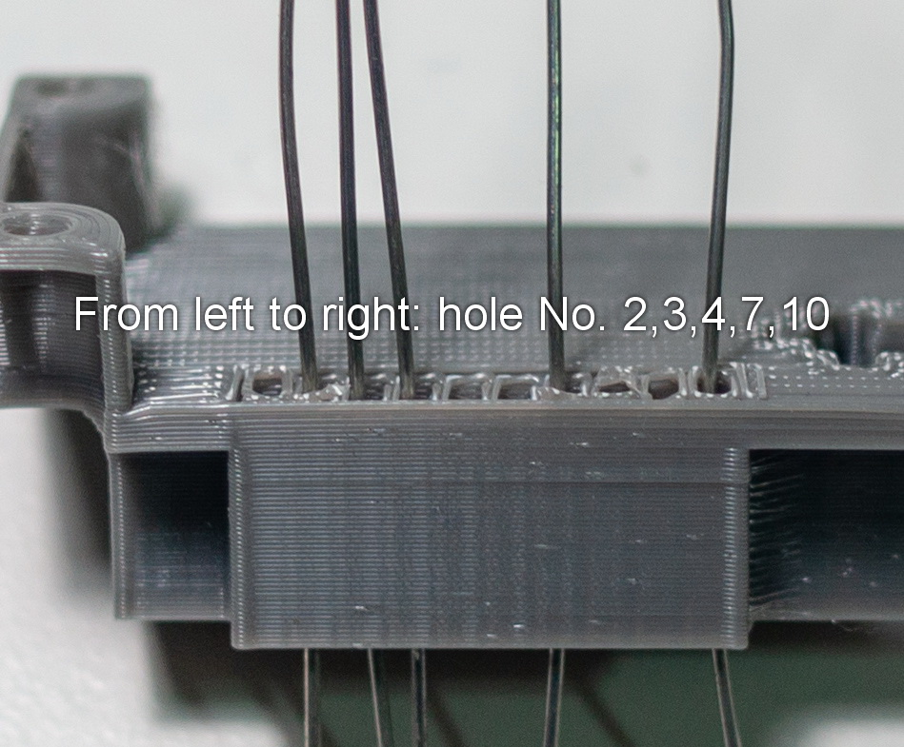
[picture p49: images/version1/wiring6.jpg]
wiring pic


Bend the wire sticking out of the hole and fold it inside. This is what contacts the keyboard connector.

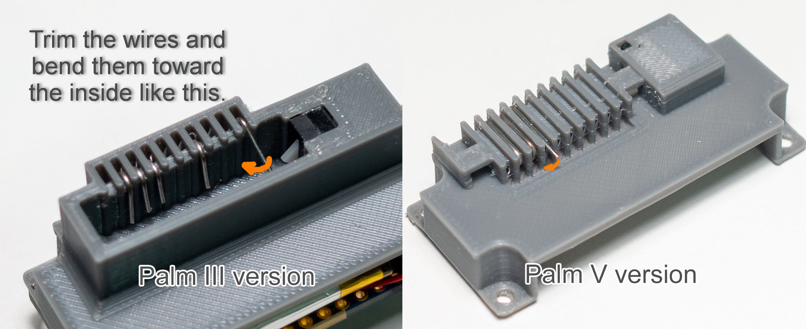
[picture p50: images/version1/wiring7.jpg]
wiring pic


Here is what the entire middle frame assembly looks like:

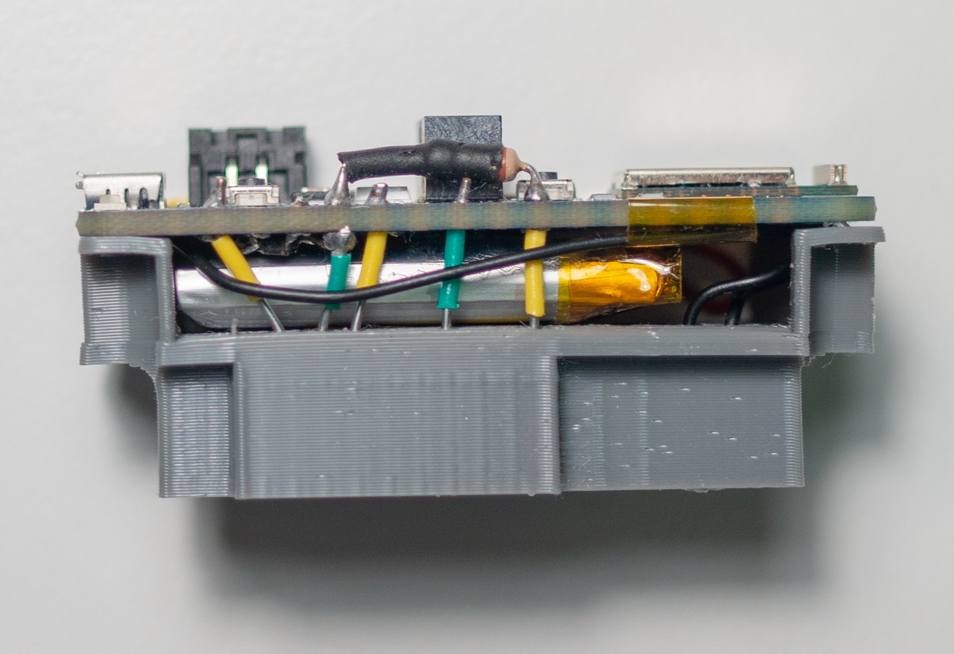
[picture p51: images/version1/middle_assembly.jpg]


Place the two buttons into the upper cap, then push the middle frame assembly into the cap. Make sure it is the correct orientation (the buttons should align with the buttons on the board).

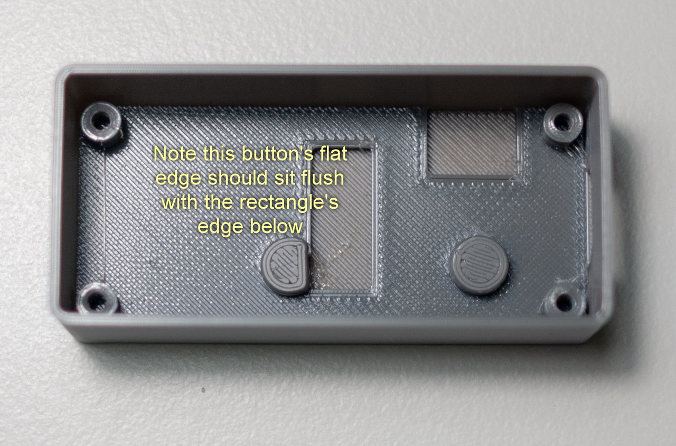
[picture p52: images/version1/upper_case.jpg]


Screw the 4 screws, and you are done!

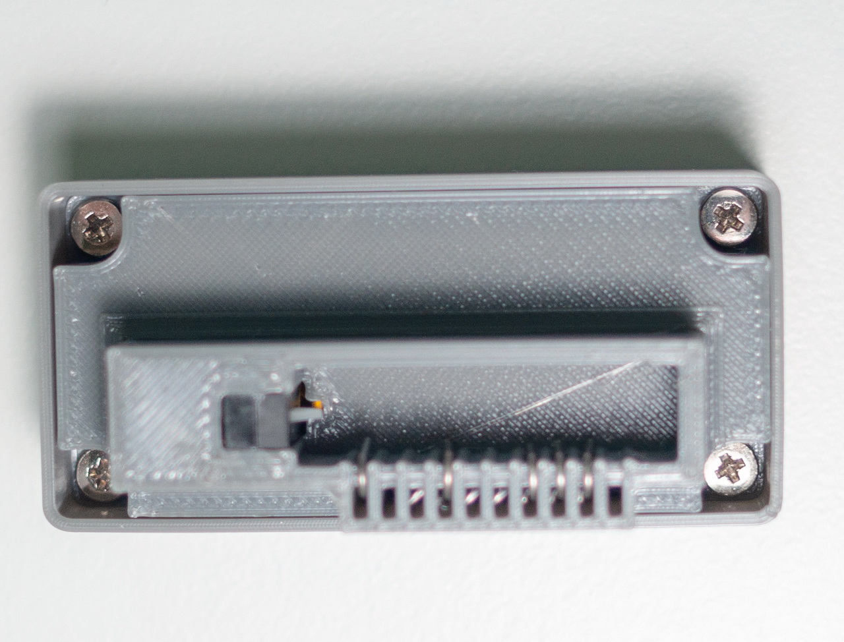
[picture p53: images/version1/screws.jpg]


Fully assembled unit:

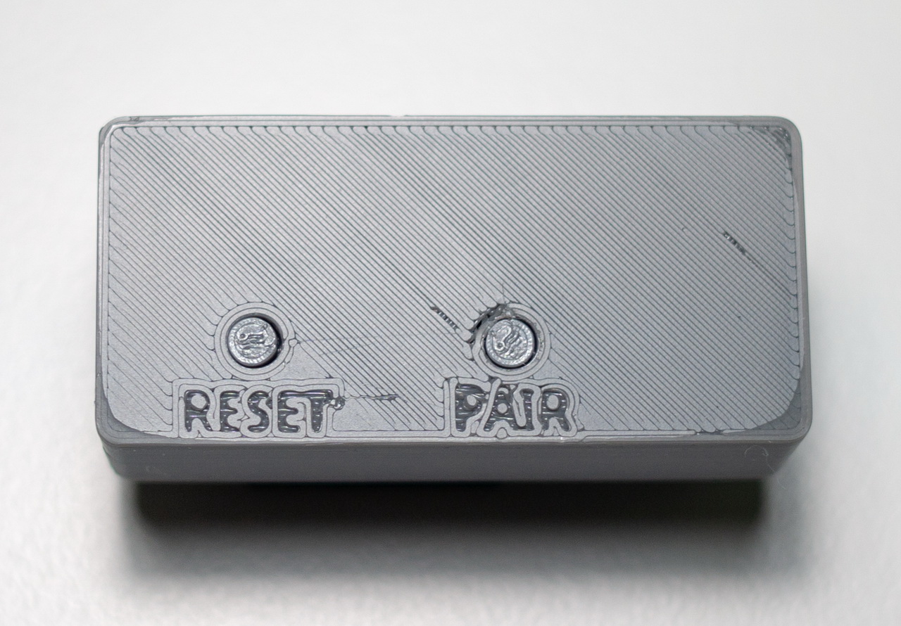
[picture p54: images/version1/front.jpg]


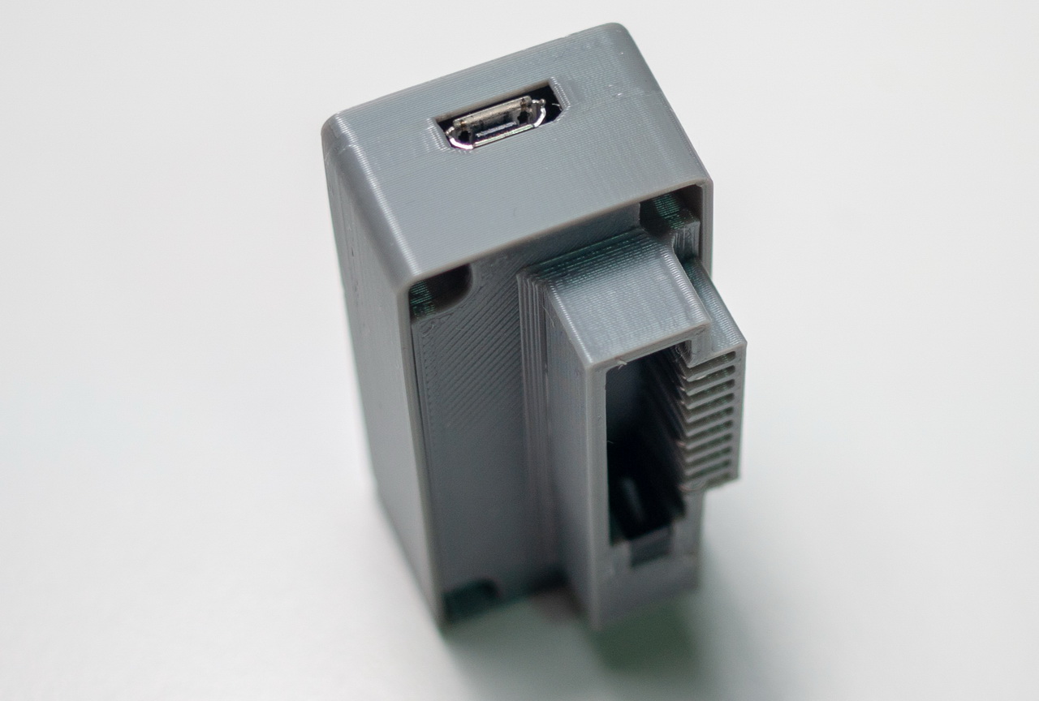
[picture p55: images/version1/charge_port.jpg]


Programming
-----------
If you have never programmed the Adafruit Feather nRF52840 Express board before, please follow the official tutorial to try programming some basic examples.

https://learn.adafruit.com/introducing-the-adafruit-nrf52840-feather

Once you know how to program the nRF52840, open up `version1_nrf52840.ino`, plug in the Micro USB cable, and hit upload, wait for the programming to be done. Then you can test it on the keyboard!

Features and quirks
---------------------
- The red LED blinks when the battery is below 60%. It double-blinks when the battery is below 40%, and triple-blinks when the battery is below 20%.
- Long press the "PAIR" button for 1 second to clear all the remembered devices on the adapter, then you can press the "RESET" button to start the pairing again.
- Press both the "RESET" and "PAIR" button and release both, the board enters DFU mode to allow force firmware update, this is useful if the current firmware is corrupted.
- Due to the way the switch is installed, the adapter can only be charged when it is plugged onto the keyboard.
- It can only connect to one device at a time. It auto connects to the last device it is paired to (if that device is in range). You can manually disconnect it in the last connected device's operating system, then you can connect it to another device.
- The stand on the PPK itself can be used to support a phone. My phone is heavy (an iPhone 12 Pro Max) but it seems to support it OK. A TPU/rubber phone case would be ideal to prevent sliding.

Possible improvements
---------------------

On some devices (my Thinkpad laptop with Debian, and Oneplus 5T, for example), the host receives key reports very slowly (almost as low as 10 reports per second). I have added a coalescing method in the software to alleviate it. But the reason of the slowness is still unknown. If you know why the slowness happens, please let me know by opening an issue.

It's possible to support USB HID, so it can be used with both USB and Bluetooth, and even switch on-the-fly by hot-keys.

Adding support for battery service is also possible.

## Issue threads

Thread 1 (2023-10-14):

Which Palm keyboard models is this likely to work with?

jkesselm, 2023-10-14:
Since Palm changed the connector a few times, there are a couple of different generations of keyboard out there. Mine's from the Palm 3 days, I believe... Any chance your solution will work with it, or can be easily adapted to it?

Palm (tm) Portable Keyboard
Designed by Think Outside, Inc.
Carlsbad, CA, USA

S/N: A0PE15E1A0A2
P10802U

(Previous USB solutions, alas, did not offer a version compatible with this keyboard model, and I have enough other projects in progress that I'd rather not do a redesign myself.)

Thanks in advance!

pymo, 2023-10-17:
Please see the README.md on the front page for supported models. Palm Universal connector is not supported due to its very small pitch. But others have tried to make an adapter for it using DIY PCBs. See https://hackaday.io/project/181800-palm-pilot-keyboard-bluetooth-conversion

Closed 2023-10-17.

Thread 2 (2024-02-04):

Code compile issue: “not declared in this scope”

phyl7h, 2024-02-04:
Hi Pymo — thanks so much for this amazing project. I have had a Palm V keyboard waiting for this moment for 20 years.

I am a complete novice with Arduino and C++, and am having trouble compiling the code.

When I run the compile and upload, I get errors around line 586, in function “esp_sleep_wakeup_cause_t SleepAndWaitForWakeup()”. Arduino IDE advises:

> error:’gpio_hold_en’ was not declared in this scope; did you mean ‘gpio_mode_t’?

It gives similar errors for ‘gpio_wakeup_enable’ and ‘gpio_hold_dis’ - they were “not declared in this scope.”

Grateful for any help you can offer.

pymo, 2024-05-03:
Hi,
It looks like the esp32 dependency is not found. Did you install the esp32 board dependency as instructed in the tutorial?

phyl7h, 2024-05-12:
Thanks so much for the help Pymo. I thought I had installed that dependency but must not have. I removed and reinstalled Arduino IDE and all dependencies and the code installed without issue. Off to the races!

phyl7h, 2024-05-26:
Hi Pymo — wanted to let you know that the code worked perfectly, and share my build.

I wanted to fit everything on the keyboard itself without the need for an adapter. So I got rid of the slide-out stand to make room for a 304050 lipo (3mm thick). I also used an ESP32 C3 Mini board (https://a.aliexpress.com/_mLrhPGO). After using a Dremel to grind-down the plastic Palm dock there was room to just epoxy the new board directly to it. I used magnet wire for the leads to save bulk. I’m very happy that it actually folds.

Thanks again for the inspiration and the code.

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

pymo, 2024-05-28:
Thanks for sharing! I didn't have the nerve to dremel the connector off, so I went with the adapter route.

Also I couldn't find a small enough board that has li-po charger integrated (I believe your board didn't either?), so I actually started designing my own PCB, not based on ESP32-C3 but based on WCH CH582F. That should be small enough and have all the features needed to charge li-po. Stay tuned to this project if you are interested!

Closed 2024-05-12.

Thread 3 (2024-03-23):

Map right alt-gr key

ihewitt, 2024-03-23:
Not really an issue, but just a quick addition didn't seem worth creating a fork and a PR just for this! Since the Palm is US layout, I found it useful to add a mapping at "Space2" for AltGr so I can use the InternationalUS layout to be able to type, for example "£" (Shift-AltGr-4)
€ etc.
[US International layout](https://en.wikipedia.org/wiki/QWERTY#US-International)

-#ifdef GERMAN_LAYOUT
+#if defined(GERMAN_LAYOUT)
   key_map[0b00110111] = '`';  // "Space 2"
+#elif defined(ALTGR_LAYOUT)
+  key_map[0b00110111] = KEY_RIGHT_ALT;  // "Space 2"
 #else
   key_map[0b00110111] = ' ';  // "Space 2"
 #endif

pymo, 2024-05-03:
There is an actual German version of the PPK, and the AltGr is not on the Space key's location. The GERMAN_LAYOUT macro in my code is to support that keyboard. See the pic attached.

I guess your purpose is to type German characters using a US layout. You can make the change on your side, but I'd prefer not include it in the repo. Sorry...

Another suggestion: when you want to type a space with your right thumb, there is a high chance that it lands on the “Space/New” key due to its position, so mapping it to other keys may hurdle your typing. A better solution would be mapping the Done/Cancel key to AltGr (it was originally mapped to Insert). Then map Fn+ Del to be Insert.
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

ihewitt, 2024-05-15:
no worries, yes since there wasn't a UK version this is using a US layout keyboard so making use of the "US international" layout makes sense. As for the lcoation, on intl keyboards it's normal for Alt-Gr to be directly to the right of the spacebar so once you have been using the Alt-Gr combos it feels natural being there.
happy to keep the changes local.
I'm having some "lag/double key" issues at the moment to diagnosee, not sure whats going on.

Closed 2024-05-03.

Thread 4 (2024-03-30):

DCD high detected too early when Vcc goes up

jan-gerard, 2024-03-30:
Initially, I could not get it to work. It appears that with my esp32-C3, the DCD input sees a positive peak when Vcc to the keyboard is switched on. Then, the software detects this spike as the DCD pulse, and gives the RTS pulse. But that appears to be too soon, and the keyboard doesn't see it, so it doesn't send its ID.
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

When I introduce a small delay of 2 ms after the Vcc and Gnd pins to the keyboard are enabled, it works like a charm. So I would suggest to introduce such a delay in the code, after the line `digitalWrite(VCC_PIN, HIGH);`.

pymo, 2024-05-03:
That's fantastic analysis! I don't have a oscilloscope, could you help me understand: when the keyboard respond with DCD pulse, is it a pulse (i.e. 0-1-0), or it is jumping from 0 to constant high?

My fear is if it is a pulse, and I wait for too long, the code might miss the DCD pulse.

jan-gerard, 2024-05-04:
It's a pulse indeed. What happens is that 560 ms after the power is supplied to the keyboard, the DCD line goes high for 200 ms. Then it remains low for 1.5 s, and another 200 ms pulse follows. I don't know if more pulses occur, because after 4.2 s, the esp switches off the power to the keyboard. But I think this is already enough information.
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
As long as the esp does not miss the 200 ms pulse, it's OK. Typically the processor sends the RTS signal almost immediately after the DCD high was detected, making the keyboard drop the DCD again.
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

pymo, 2024-05-17:
Thanks for the graph! It is very helpful. If the DCD consistently do the pulse ~500 ms after the power, then yes, sleeping for 20ms at the beginning seems safe. I'll verify the behavior and change the code soon.

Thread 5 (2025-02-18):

keyboard map representations

clach04, 2025-02-18:
Any interest in some code/visualizations for the keyboard(s)?

I put together a quick on (using reversed colors for easier printing) using https://www.keyboard-layout-editor.com/ https://github.com/ijprest/keyboard-layout-editor/

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

Using this json file.
[palm-3c10317.json](https://github.com/user-attachments/files/18838293/palm-3c10317.json)

The Pocket PC physical layout in terms of key positions the same BUT different mappings silk printed on the keys.

I'm hoping to code up a script to map the json to C code in the driver code in https://github.com/pymo/wch_micro_kbd

clach04, 2025-02-18:
I'm also contemplating the reverse, C code to JSON for visualization. E.g. key8_table in https://github.com/pymo/wch_micro_kbd/blob/main/src/drivers/key_scan/key_table.c

https://github.com/pymo/wch_micro_kbd/blob/main/src/drivers/key_scan/key_table.c#L108..L122

clach04, 2025-02-19:
An Pocket PC / Windows Mobile

[targus-stowaway-hp-jornada-pa820.json](https://github.com/user-attachments/files/18858520/targus-stowaway-hp-jornada-pa820.json)

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

clach04, 2025-02-19:
Palm with ppk fn mappings

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

[palm-3c10317-for-ppk-bluetooth.json](https://github.com/user-attachments/files/18858691/palm-3c10317-for-ppk-bluetooth.json)

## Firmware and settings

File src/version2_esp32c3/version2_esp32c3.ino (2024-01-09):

/**
   This code converts the Palm Portable Keyboard's output into bluetooth.
   See https://github.com/pymo/ppk_bluetooth for details.

*/

#include <driver/uart.h>
#include <esp_sleep.h>

#include "BleKeyboard.h"

// Uncomment to enable debug output through the arduino console at speed 115200n1;
// Comment out to disable debug output.
// #define PPK_DEBUG

// Uncomment to compile firmware for Handspring keyboard;
// Comment out to compile firmware for Palm III, V or M500 keyboard.
// #define HANDSPRING

// Uncomment to put the firmware in battery test mode. It prints
// the raw battery reading to the bluetooth host. It also disables the
// sleep function.
// #define BATTERY_TEST_MODE

// #define GERMAN_LAYOUT

#ifdef HANDSPRING
// Handspring pinout
#define VCC_PIN 4
#define GND_PIN 6
#define RX_PIN 10
#define TX_PIN 19
#define HEX_ID0 0xF9
#define HEX_ID1 0xFB
#define INVERT_TTL false
#else
// Palm III, V or m500 pinout
#define VCC_PIN 4
#define RTS_PIN 6
#define DCD_PIN 7
#define GND_PIN 10
#define RX_PIN 5
#define TX_PIN 19
#define HEX_ID0 0xFA
#define HEX_ID1 0xFD
#define INVERT_TTL true
#endif

#define BATTERY_ADC_PIN 2
#define BATTERY_LED 8
#define FUNC_LED 3

void ledOff(uint8_t pin) {
  pinMode(pin, OUTPUT);
  digitalWrite(pin, LOW);
}
void ledOn(uint8_t pin) {
  pinMode(pin, OUTPUT);
  digitalWrite(pin, HIGH);
}

// wait this many milliseconds before making sure keyboard is still awake
#define KEEPALIVE_TIMEOUT 500000

// if the keyboard has been idled for 30 min, enter light sleep.
#define IDLE_TIMEOUT 1800000

// if the keyboard can not initialize after 4 seconds, reboot the board.
#define KEYBOARD_INIT_TIMEOUT 4000

// Conversion factor for micro seconds to mili seconds
#define uS_TO_mS_FACTOR 1000

BleKeyboard bleKeyboard(/*deviceName=*/"Palm Keyboard",
                        /*deviceManufacturer=*/"Xinming Chen");

char key_map[128] = {0};
char fn_key_map[128] = {0};

char last_byte = 0;

// The timestamp of the last time the keyboard has communicated with the board.
unsigned long last_comm = 0;
// The timestamp of the last time there is a key been pressed.
unsigned long last_pressed = 0;

void config_keymap() {
  // y0 row
  key_map[0b00000000] = '1';
  key_map[0b00000001] = '2';
  key_map[0b00000010] = '3';
  key_map[0b00000011] = 'z';
  key_map[0b00000100] = '4';
  key_map[0b00000101] = '5';
  key_map[0b00000110] = '6';
  key_map[0b00000111] = '7';

  // y1 row
  key_map[0b00001000] = KEY_LEFT_GUI;  // "CMMD" or "Cmd"
  key_map[0b00001001] = 'q';
  key_map[0b00001010] = 'w';
  key_map[0b00001011] = 'e';
  key_map[0b00001100] = 'r';
  key_map[0b00001101] = 't';
  key_map[0b00001110] = 'y';
#ifdef GERMAN_LAYOUT
  key_map[0b00001111] = KEY_OEM_102;  // German <>| key
#else
  key_map[0b00001111] = '`';
#endif

  // y2 row
  key_map[0b00010000] = 'x';
  key_map[0b00010001] = 'a';
  key_map[0b00010010] = 's';
  key_map[0b00010011] = 'd';
  key_map[0b00010100] = 'f';
  key_map[0b00010101] = 'g';
  key_map[0b00010110] = 'h';
  key_map[0b00010111] = ' ';  // "Space 1"

  // y3 row
  key_map[0b00011000] = KEY_CAPS_LOCK;
  key_map[0b00011001] = KEY_TAB;
  key_map[0b00011010] = KEY_LEFT_CTRL;
  key_map[0b00011011] = 0;
  key_map[0b00011100] = 0;
  key_map[0b00011101] = 0;
  key_map[0b00011110] = 0;
  key_map[0b00011111] = 0;

  // y4 row
  key_map[0b00100000] = 0;
  key_map[0b00100001] = 0;
  key_map[0b00100010] = 0;  // Fn key
  key_map[0b00100011] = KEY_LEFT_ALT;
  key_map[0b00100100] = 0;
  key_map[0b00100101] = 0;
  key_map[0b00100110] = 0;
  key_map[0b00100111] = 0;

  // y5 row
  key_map[0b00101000] = 0;
  key_map[0b00101001] = 0;
  key_map[0b00101010] = 0;
  key_map[0b00101011] = 0;
  key_map[0b00101100] = 'c';
  key_map[0b00101101] = 'v';
  key_map[0b00101110] = 'b';
  key_map[0b00101111] = 'n';

  // y6 row
  key_map[0b00110000] = '-';
  key_map[0b00110001] = '=';
  key_map[0b00110010] = KEY_BACKSPACE;
  key_map[0b00110011] = KEY_HOME;  // "Special Function One"
  key_map[0b00110100] = '8';
  key_map[0b00110101] = '9';
  key_map[0b00110110] = '0';
#ifdef GERMAN_LAYOUT
  key_map[0b00110111] = '`';  // "Space 2"
#else
  key_map[0b00110111] = ' ';  // "Space 2"
#endif

  // y7 row
  key_map[0b00111000] = '[';
  key_map[0b00111001] = ']';
  key_map[0b00111010] = '\\';
  key_map[0b00111011] = KEY_END;  // "Special Function Two"
  key_map[0b00111100] = 'u';
  key_map[0b00111101] = 'i';
  key_map[0b00111110] = 'o';
  key_map[0b00111111] = 'p';

  // y8 row
  key_map[0b01000000] = '\'';
  key_map[0b01000001] = KEY_RETURN;
  key_map[0b01000010] = KEY_PAGE_UP;  // "Special Function Three"
  key_map[0b01000011] = 0;
  key_map[0b01000100] = 'j';
  key_map[0b01000101] = 'k';
  key_map[0b01000110] = 'l';
  key_map[0b01000111] = ';';

  // y9 row
  key_map[0b01001000] = '/';
  key_map[0b01001001] = KEY_UP_ARROW;
  key_map[0b01001010] = KEY_PAGE_DOWN;  // "Special Function Four"
  key_map[0b01001011] = 0;
  key_map[0b01001100] = 'm';
  key_map[0b01001101] = ',';
  key_map[0b01001110] = '.';
#ifdef GERMAN_LAYOUT
  key_map[0b01001111] = KEY_RIGHT_ALT;  // "DONE" or "Done"
#else
  key_map[0b01001111] = KEY_INSERT;  // "DONE" or "Done"
#endif

  // y10 row
  key_map[0b01010000] = KEY_DELETE;
  key_map[0b01010001] = KEY_LEFT_ARROW;
  key_map[0b01010010] = KEY_DOWN_ARROW;
  key_map[0b01010011] = KEY_RIGHT_ARROW;
  key_map[0b01010100] = 0;
  key_map[0b01010101] = 0;
  key_map[0b01010110] = 0;
  key_map[0b01010111] = 0;

  // y11 row
  key_map[0b01011000] = KEY_LEFT_SHIFT;
  key_map[0b01011001] = KEY_RIGHT_SHIFT;
  key_map[0b01011010] = 0;
  key_map[0b01011011] = 0;
  key_map[0b01011100] = 0;
  key_map[0b01011101] = 0;
  key_map[0b01011110] = 0;
  key_map[0b01011111] = 0;
}

void config_fnkeymap() {
  fn_key_map[0b00011001] = KEY_ESC;  // tab key
  fn_key_map[0b00000000] = KEY_F1;   // 1
  fn_key_map[0b00000001] = KEY_F2;   // 2
  fn_key_map[0b00000010] = KEY_F3;   // 3
  fn_key_map[0b00000100] = KEY_F4;   // 4
  fn_key_map[0b00000101] = KEY_F5;   // 5
  fn_key_map[0b00000110] = KEY_F6;   // 6
  fn_key_map[0b00000111] = KEY_F7;   // 7
  fn_key_map[0b00110100] = KEY_F8;   // 8
  fn_key_map[0b00110101] = KEY_F9;   // 9
  fn_key_map[0b00110110] = KEY_F10;  // 0
  fn_key_map[0b00110000] = KEY_F11;  // -
  fn_key_map[0b00110001] = KEY_F12;  // =
#ifdef GERMAN_LAYOUT
  fn_key_map[0b01010000] = KEY_INSERT;   // KEY_DELETE
#endif
}

void boot_keyboard() {
#ifdef PPK_DEBUG
  Serial.println("beginning keyboard boot sequence");
#endif

#ifdef HANDSPRING
  pinMode(RX_PIN, INPUT_PULLUP);
#else
  pinMode(DCD_PIN, INPUT);
  pinMode(RTS_PIN, INPUT);
  pinMode(RX_PIN, INPUT_PULLDOWN);
#endif

  pinMode(VCC_PIN, OUTPUT);
  digitalWrite(VCC_PIN, LOW);
  pinMode(GND_PIN, OUTPUT);
  digitalWrite(GND_PIN, LOW);
  delay(100);
  digitalWrite(VCC_PIN, HIGH);

  int start_time = millis();
#ifndef HANDSPRING
  while (digitalRead(DCD_PIN) != HIGH) {
    if (millis() - start_time > KEYBOARD_INIT_TIMEOUT) {
#ifdef PPK_DEBUG
      Serial.print(
          "Keyboard not pulling up DCD, bad keyboard? Rebooting...");
#endif
      ESP.restart();
    }
    delay(1);
  };

#ifdef PPK_DEBUG
  Serial.println("DCD_PIN response done");
#endif

  if (digitalRead(RTS_PIN) == LOW) {
    delay(10);
    pinMode(RTS_PIN, OUTPUT);
    digitalWrite(RTS_PIN, HIGH);
  } else {
    pinMode(RTS_PIN, OUTPUT);
    digitalWrite(RTS_PIN, HIGH);
    digitalWrite(RTS_PIN, LOW);
    delay(10);
    digitalWrite(RTS_PIN, HIGH);
  }
#endif  // #ifndef HANDSPRING

#ifdef PPK_DEBUG
  Serial.print("waiting for keyboard serial ID... ");
#endif

  // Read the Hardware Serial1 until we get the expected hex ID. Due to the
  // timing of plugging in the adapter, there could be garbage chars before the
  // ID, the following code will ignore them.
  int byte1, byte2 = 0;
  while (true) {
    delay(10);
    if (Serial1.available()) {
      byte1 = byte2;
      byte2 = Serial1.read();
#ifdef PPK_DEBUG
      Serial.print(byte2);
      Serial.print(" ");
#endif
    }
    if ((byte1 == HEX_ID0) && (byte2 == HEX_ID1)) break;
    if (millis() - start_time > KEYBOARD_INIT_TIMEOUT) {
#ifdef PPK_DEBUG
      Serial.print(
          "No keyboard ID received, something is wrong, rebooting the board.");
#endif
      ESP.restart();
    }
  }

#ifdef PPK_DEBUG
  Serial.println(" done");
#endif
}

void setup() {
  setCpuFrequencyMhz(80);
#ifdef PPK_DEBUG
  Serial.begin(115200);
#endif
  ledOn(BATTERY_LED);
  ledOn(FUNC_LED);
  CheckBatteryWithInterval();
  // The adapter may have just been plugged in and is not fully contacting
  // with the keyboard's golden fingers yet. Wait for 0.5s before doing anything.
  delay(500);

  Serial1.begin(9600, SERIAL_8N1, RX_PIN, TX_PIN, /*invert=*/INVERT_TTL);

  config_keymap();
  config_fnkeymap();
  boot_keyboard();
  ledOff(BATTERY_LED);
  bleKeyboard.begin();
#ifdef PPK_DEBUG
  Serial.println("setup completed");
#endif
}

bool fn_key_down = false;

void ReportKeyUpDownEvent(uint8_t key_code, bool key_up) {
  if (key_up) {
    bleKeyboard.release(key_code);
  } else {
    bleKeyboard.press(key_code);
  }
}

void PrintStringToKeyboard(char *str) {
  for (int i = 0; i < strlen(str); ++i) {
    char to_be_sent = str[i];
    if (to_be_sent < 32 || to_be_sent > 126) to_be_sent = ' ';
    ReportKeyUpDownEvent(to_be_sent, /*key_up=*/false);
    delay(10);
    ReportKeyUpDownEvent(to_be_sent, /*key_up=*/true);
    delay(5);
  }
}
void ResetKeyUpDownEvent() { bleKeyboard.releaseAll(); }

// convenience masks
#define UPDOWN_MASK 0b10000000
#define MAP_MASK 0b01111111

void HandleKeyEvent(uint8_t key_byte) {
  bool key_up = ((key_byte & UPDOWN_MASK) != 0);
  uint8_t masked_key_byte = key_byte & MAP_MASK;
  uint8_t key_code = 0;

  if (fn_key_down) {
    if (fn_key_map[masked_key_byte]) key_code = fn_key_map[masked_key_byte];
  } else {
    key_code = key_map[masked_key_byte];
  }

  // keyboard duplicates the final key-up byte
  if (key_byte == last_byte) {
    ResetKeyUpDownEvent();
  } else {
    if (key_code != 0) {
      ReportKeyUpDownEvent(key_code, key_up);
    } else {
      // special case the Fn key
      if ((masked_key_byte) == 34) {
        fn_key_down = !key_up;
      }
    }
  }

  // Handles the Volume and Brightness keys in the end, they are using consumer
  // report.
  if (fn_key_down) {
    MediaKeyReport media_key_report = {0, 0};
    if (masked_key_byte == 0b01010001)
      memcpy(media_key_report, KEY_MEDIA_BRIGHTNESS_DOWN,
             sizeof(media_key_report));  // left arrow
    else if (masked_key_byte == 0b01010010)
      memcpy(media_key_report, KEY_MEDIA_VOLUME_DOWN,
             sizeof(media_key_report));  // down arrow
    else if (masked_key_byte == 0b01010011)
      memcpy(media_key_report, KEY_MEDIA_BRIGHTNESS_UP,
             sizeof(media_key_report));  // right arrow
    else if (masked_key_byte == 0b01001001)
      memcpy(media_key_report, KEY_MEDIA_VOLUME_UP,
             sizeof(media_key_report));  // up arrow
    else if (masked_key_byte == 0b00001000)
      memcpy(media_key_report, KEY_MEDIA_WWW_HOME,
             sizeof(media_key_report));  // Fn+CMD=iOS Home button
    if (media_key_report[0] != 0 || media_key_report[1] != 0) {
      if (key_up)
        bleKeyboard.release(media_key_report);
      else
        bleKeyboard.press(media_key_report);
    }
  }
  last_byte = key_byte;
#ifdef PPK_DEBUG
  Serial.printf("%s %u\n", key_up ? "released" : "pressed",
                (unsigned int)masked_key_byte);
#endif
  last_comm = millis();
  last_pressed = millis();
}

/*  Battery function
    The current consumption of the entire board measured from the battery
   connector:
   79mA 160MHz normal operation
   73.6mA 80MHz normal operation
   15.6mA Bluetooth off
   1.78mA Light sleep
   19.6uA power switch off
*/
#define BAT_CHECK_INTERVAL 60000  // 60 seconds
unsigned long last_battery_check_time = 0;

// The ADC of ESP32-C3 is not linear to the voltage... so we don't bother
// converting the raw value to volts. We just measure the raw value across the
// entire run time, then we can calculate the raw reading at 0%, 5%, ..., 100%
// battery life. It is a rough estimation anyway.
//
// If you are using a different ESP32 board, you may need to change this table.
// This lookup table must have 21 entries. Each entry must be different,
// otherwise we will have divide-by-zero error below.
int bat_percent_lookup[] = {2000, 2340, 2390, 2420, 2450, 2475, 2490,
                            2505, 2520, 2530, 2550, 2570, 2600, 2645,
                            2675, 2705, 2740, 2770, 2805, 2845, 2905};
LedBlinkPattern battery_led_pattern = LED_NO_BLINK;

void CheckBatteryWithInterval() {
  int current_time = millis();
  if ((last_battery_check_time != 0) &&
      (current_time - last_battery_check_time < BAT_CHECK_INTERVAL))
    return;

  int raw_bat_data = analogRead(BATTERY_ADC_PIN);
#ifdef BATTERY_TEST_MODE
  char volt_str[50];
  sprintf(volt_str, "%d ", raw_bat_data);
  PrintStringToKeyboard(volt_str);
#endif
  int battery_level = -1;  // percentage of the battery
  int n;
  for (n = 0; n <= 20; n++) {
    if (raw_bat_data < bat_percent_lookup[n]) {
      if (n == 0) {
        battery_level = 0;
        break;
      } else {
        // raw_bat_data falls between bat_percent_lookup[n-1] and
        // bat_percent_lookup[n]. Do interpolation.
        battery_level = 5 * (n - 1) +
                        5 * (raw_bat_data - bat_percent_lookup[n - 1]) /
                            (bat_percent_lookup[n] - bat_percent_lookup[n - 1]);
        break;
      }
    }
  }
  if (n > 20) {
    battery_level = 100;
  }
#ifdef PPK_DEBUG
  Serial.printf("Battery percentage %d, raw_data = %d\n", battery_level,
                raw_bat_data);
#endif
  bleKeyboard.setBatteryLevel(battery_level);
  if (battery_level >= 20)
    battery_led_pattern = LED_NO_BLINK;
  else if (battery_level >= 15 && battery_level < 20)
    battery_led_pattern = LED_BLINK_ONCE;
  else if (battery_level >= 10 && battery_level < 15)
    battery_led_pattern = LED_BLINK_TWICE;
  else if (battery_level < 10)
    battery_led_pattern = LED_BLINK_THREE_TIMES;
  last_battery_check_time = current_time;
}

LedBlinkPattern func_led_pattern = LED_ALWAYS_ON;
unsigned long current_time = 0;

void CheckConnectionStatus() {
  if (bleKeyboard.isConnected())
    func_led_pattern = LED_BLINK_ONCE;
  else
    func_led_pattern = LED_BLINK_QUICK;
}

void HandleFuncLedBlink(uint8_t pin) {
  current_time = millis();

  switch (func_led_pattern) {
    case LED_NO_BLINK:
      ledOff(pin);
      break;
    case LED_ALWAYS_ON:
      ledOn(pin);
      break;
    case LED_BLINK_QUICK:
      if (current_time % 140 < 50)
        ledOn(pin);
      else
        ledOff(pin);
      break;
    case LED_BLINK_ONCE:
      if (current_time % 5000 < 50)
        ledOn(pin);
      else
        ledOff(pin);
      break;
    default:
      break;
  }
}

#define BLINK_CYCLE 3000  // 3 seconds
#define BLINK_LENGTH 50   // milliseconds
unsigned long last_cycle_start_timestamp = 0;

void HandleBatteryLedBlink(uint8_t pin) {
  current_time = millis();
  //  | On | Off | On | Off | On | Off |
  if (battery_led_pattern >= LED_BLINK_ONCE &&
      (current_time - last_cycle_start_timestamp) >
          BLINK_CYCLE) {  // Overdue for the next cycle, turn on the LED
    ledOn(pin);
    last_cycle_start_timestamp = current_time;
  } else if ((current_time - last_cycle_start_timestamp) > BLINK_LENGTH &&
             (current_time - last_cycle_start_timestamp) <= BLINK_LENGTH * 4) {
    ledOff(pin);
  } else if (battery_led_pattern >= LED_BLINK_TWICE &&
             (current_time - last_cycle_start_timestamp) > BLINK_LENGTH * 4 &&
             (current_time - last_cycle_start_timestamp) <= BLINK_LENGTH * 5) {
    ledOn(pin);
  } else if ((current_time - last_cycle_start_timestamp) > BLINK_LENGTH * 5 &&
             (current_time - last_cycle_start_timestamp) <= BLINK_LENGTH * 8) {
    ledOff(pin);
  } else if (battery_led_pattern >= LED_BLINK_THREE_TIMES &&
             (current_time - last_cycle_start_timestamp) > BLINK_LENGTH * 8 &&
             (current_time - last_cycle_start_timestamp) <= BLINK_LENGTH * 9) {
    ledOn(pin);
  } else if ((current_time - last_cycle_start_timestamp) > BLINK_LENGTH * 9) {
    ledOff(pin);
  }
}

esp_sleep_wakeup_cause_t SleepAndWaitForWakeUp() {
#ifdef PPK_DEBUG
  Serial.println("Entering light sleep.");
  /* To make sure the complete line is printed before entering sleep mode,
     need to wait until UART TX FIFO is empty:
  */
  uart_wait_tx_idle_polling(CONFIG_ESP_CONSOLE_UART_NUM);
#endif
  ledOff(BATTERY_LED);
  ledOff(FUNC_LED);
  // Holds the state of VCC, GND and RTS line so the PPK is still alive.
  // Otherwise we won't be able to wake up by key press.
  gpio_hold_en((gpio_num_t)VCC_PIN);
  gpio_hold_en((gpio_num_t)GND_PIN);
#ifndef HANDSPRING
  gpio_hold_en((gpio_num_t)RTS_PIN);
#endif
  gpio_hold_en((gpio_num_t)BATTERY_LED);
  gpio_wakeup_enable((gpio_num_t)RX_PIN,
                     INVERT_TTL ? GPIO_INTR_HIGH_LEVEL : GPIO_INTR_LOW_LEVEL);
  esp_sleep_enable_gpio_wakeup();
  // We need to wake up periodically to keep the PPK alive.
  // Otherwise the PPK goes to sleep and we won't be able to wake up by key
  // press.
  esp_sleep_enable_timer_wakeup(KEEPALIVE_TIMEOUT * uS_TO_mS_FACTOR);
  // Sleep starts, execution will continue once RX line is active, or the timer
  // is up.
  esp_light_sleep_start();
  gpio_hold_dis((gpio_num_t)VCC_PIN);
  gpio_hold_dis((gpio_num_t)GND_PIN);
#ifndef HANDSPRING
  gpio_hold_dis((gpio_num_t)RTS_PIN);
#endif
  gpio_hold_dis((gpio_num_t)BATTERY_LED);
  return esp_sleep_get_wakeup_cause();
}

void loop() {
  if (Serial1.available()) {
    for (int i = Serial1.available(); i > 0; i--) {
      HandleKeyEvent(Serial1.read());
    }
  }
  // Sleep the board if the keyboard has been idling for a long time
  bool keyboard_rebooted_in_this_cycle;
  keyboard_rebooted_in_this_cycle = false;

#ifndef BATTERY_TEST_MODE
  if ((millis() - last_comm) > IDLE_TIMEOUT) {
    esp_sleep_wakeup_cause_t wakeup_reason = SleepAndWaitForWakeUp();
    switch (wakeup_reason) {
      case ESP_SLEEP_WAKEUP_TIMER:
#ifdef PPK_DEBUG
        Serial.println(
            "Wakeup caused by timer, toogle the keyboard and sleep again.");
#endif
        boot_keyboard();
        keyboard_rebooted_in_this_cycle = true;
        // We don't update last_comm here, so in the next loop, the board will
        // enter sleep again.
        break;
      case ESP_SLEEP_WAKEUP_GPIO:
#ifdef PPK_DEBUG
        Serial.println("Wakeup caused by key press, don't go to sleep again.");
#endif
        boot_keyboard();
        last_comm = millis();
        keyboard_rebooted_in_this_cycle = true;
        break;
      default:
#ifdef PPK_DEBUG
        Serial.printf(
            "It should not happen. Wakeup was not caused by timer nor "
            "keypress: %d\n",
            wakeup_reason);
#endif
        break;
    }
  }
#endif

  // reboot if no recent keypress, otherwise keyboard falls asleep
  if (!keyboard_rebooted_in_this_cycle &&
      (millis() - last_pressed) > KEEPALIVE_TIMEOUT) {
#ifdef PPK_DEBUG
    Serial.println("rebooting keyboard for timeout");
#endif
    last_pressed = millis();
    boot_keyboard();
  }
  CheckBatteryWithInterval();
  HandleBatteryLedBlink(BATTERY_LED);
  CheckConnectionStatus();
  HandleFuncLedBlink(FUNC_LED);
  // Delay a bit after a loop to save power. We don't need too frequent key
  // detection. The hardware reference of PPK says "Filters Key Bounce: 15 - 25
  // milliseconds".
  delay(25);
}

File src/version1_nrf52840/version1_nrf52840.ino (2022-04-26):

/*********************************************************************
  This is an example for our nRF52 based Bluefruit LE modules

  Pick one up today in the adafruit shop!

  Adafruit invests time and resources providing this open source code,
  please support Adafruit and open-source hardware by purchasing
  products from Adafruit!

  MIT license, check LICENSE for more information
  All text above, and the splash screen below must be included in
  any redistribution
*********************************************************************/
#include <bluefruit.h>
#include "Adafruit_TinyUSB.h"

// Define to enable debug mode, which notes to the arduino console at 115200
// Comment out to disable debug mode.
// #define PPK_DEBUG

#define RTS_PIN       PIN_A1
#define DCD_PIN       PIN_A3
#define GND_PIN       PIN_A5

#define PAIR_BUTTON PIN_BUTTON1
#define BTN_ACTIVE LOW
#define BATTERY_ADC_PIN PIN_A6

BLEDis bledis;
BLEHidAdafruit blehid;

// wait this many milliseconds before making sure keyboard is still awake
#define TIMEOUT 500000

// wait for this many milliseconds before sending the last key up event.
#define COALESCE_WAIT 30

// macro for testing if a char is printable ASCII
#define PRINTABLE_CHAR(x) ((x >= 32) && (x <= 126))

typedef enum LedBlinkPattern {
  LED_NO_BLINK,
  LED_BLINK_ONCE,
  LED_BLINK_TWICE,
  LED_BLINK_THREE_TIMES,
} LedBlinkPattern;

//SoftwareSerial keyboard_serial(RX_PIN, TX_PIN, true); // RX, TX, inverted

char key_map[128] = { 0 };
char fn_key_map[128] = { 0 };

unsigned long last_comm = 0;

void config_keymap()
{
  // y0 row
  key_map[0b00000000] = HID_KEY_1;
  key_map[0b00000001] = HID_KEY_2;
  key_map[0b00000010] = HID_KEY_3;
  key_map[0b00000011] = HID_KEY_Z;
  key_map[0b00000100] = HID_KEY_4;
  key_map[0b00000101] = HID_KEY_5;
  key_map[0b00000110] = HID_KEY_6;
  key_map[0b00000111] = HID_KEY_7;

  // y1 row
  key_map[0b00001000] = HID_KEY_GUI_LEFT; // "CMMD" or "Cmd"
  key_map[0b00001001] = HID_KEY_Q;
  key_map[0b00001010] = HID_KEY_W;
  key_map[0b00001011] = HID_KEY_E;
  key_map[0b00001100] = HID_KEY_R;
  key_map[0b00001101] = HID_KEY_T;
  key_map[0b00001110] = HID_KEY_Y;
  key_map[0b00001111] = HID_KEY_GRAVE;

  // y2 row
  key_map[0b00010000] = HID_KEY_X;
  key_map[0b00010001] = HID_KEY_A;
  key_map[0b00010010] = HID_KEY_S;
  key_map[0b00010011] = HID_KEY_D;
  key_map[0b00010100] = HID_KEY_F;
  key_map[0b00010101] = HID_KEY_G;
  key_map[0b00010110] = HID_KEY_H;
  key_map[0b00010111] = HID_KEY_SPACE; // "Space 1"

  // y3 row
  key_map[0b00011000] = HID_KEY_CAPS_LOCK;
  key_map[0b00011001] = HID_KEY_TAB;
  key_map[0b00011010] = HID_KEY_CONTROL_LEFT;
  key_map[0b00011011] = 0;
  key_map[0b00011100] = 0;
  key_map[0b00011101] = 0;
  key_map[0b00011110] = 0;
  key_map[0b00011111] = 0;

  // y4 row
  key_map[0b00100000] = 0;
  key_map[0b00100001] = 0;
  key_map[0b00100010] = 0; // Fn key
  key_map[0b00100011] = HID_KEY_ALT_LEFT;
  key_map[0b00100100] = 0;
  key_map[0b00100101] = 0;
  key_map[0b00100110] = 0;
  key_map[0b00100111] = 0;

  // y5 row
  key_map[0b00101000] = 0;
  key_map[0b00101001] = 0;
  key_map[0b00101010] = 0;
  key_map[0b00101011] = 0;
  key_map[0b00101100] = HID_KEY_C;
  key_map[0b00101101] = HID_KEY_V;
  key_map[0b00101110] = HID_KEY_B;
  key_map[0b00101111] = HID_KEY_N;

  // y6 row
  key_map[0b00110000] = HID_KEY_MINUS;
  key_map[0b00110001] = HID_KEY_EQUAL;
  key_map[0b00110010] = HID_KEY_BACKSPACE;
  key_map[0b00110011] = HID_KEY_HOME; // "Special Function One"
  key_map[0b00110100] = HID_KEY_8;
  key_map[0b00110101] = HID_KEY_9;
  key_map[0b00110110] = HID_KEY_0;
  key_map[0b00110111] = HID_KEY_SPACE; // "Space 2" as Space

  // y7 row
  key_map[0b00111000] = HID_KEY_BRACKET_LEFT;
  key_map[0b00111001] = HID_KEY_BRACKET_RIGHT;
  key_map[0b00111010] = HID_KEY_BACKSLASH;
  key_map[0b00111011] = HID_KEY_END; // "Special Function Two"
  key_map[0b00111100] = HID_KEY_U;
  key_map[0b00111101] = HID_KEY_I;
  key_map[0b00111110] = HID_KEY_O;
  key_map[0b00111111] = HID_KEY_P;

  // y8 row
  key_map[0b01000000] = HID_KEY_APOSTROPHE;
  key_map[0b01000001] = 0x28;  //Return
  key_map[0b01000010] = HID_KEY_PAGE_UP; // "Special Function Three"
  key_map[0b01000011] = 0;
  key_map[0b01000100] = HID_KEY_J;
  key_map[0b01000101] = HID_KEY_K;
  key_map[0b01000110] = HID_KEY_L;
  key_map[0b01000111] = HID_KEY_SEMICOLON;

  // y9 row
  key_map[0b01001000] = HID_KEY_SLASH;
  key_map[0b01001001] = HID_KEY_ARROW_UP;
  key_map[0b01001010] = HID_KEY_PAGE_DOWN; // "Special Function Four"
  key_map[0b01001011] = 0;
  key_map[0b01001100] = HID_KEY_M;
  key_map[0b01001101] = HID_KEY_COMMA;
  key_map[0b01001110] = HID_KEY_PERIOD;
  key_map[0b01001111] = HID_KEY_INSERT; // "DONE" as Insert

  // y10 row
  key_map[0b01010000] = HID_KEY_DELETE;
  key_map[0b01010001] = HID_KEY_ARROW_LEFT;
  key_map[0b01010010] = HID_KEY_ARROW_DOWN;
  key_map[0b01010011] = HID_KEY_ARROW_RIGHT;
  key_map[0b01010100] = 0;
  key_map[0b01010101] = 0;
  key_map[0b01010110] = 0;
  key_map[0b01010111] = 0;

  // y11 row
  key_map[0b01011000] = HID_KEY_SHIFT_LEFT;
  key_map[0b01011001] = HID_KEY_SHIFT_RIGHT;
  key_map[0b01011010] = 0;
  key_map[0b01011011] = 0;
  key_map[0b01011100] = 0;
  key_map[0b01011101] = 0;
  key_map[0b01011110] = 0;
  key_map[0b01011111] = 0;
}

void config_fnkeymap()
{
  fn_key_map[0b00011001] = HID_KEY_ESCAPE; // tab key
  fn_key_map[0b00000000] = HID_KEY_F1; // 1
  fn_key_map[0b00000001] = HID_KEY_F2; // 2
  fn_key_map[0b00000010] = HID_KEY_F3; // 3
  fn_key_map[0b00000100] = HID_KEY_F4; // 4
  fn_key_map[0b00000101] = HID_KEY_F5; // 5
  fn_key_map[0b00000110] = HID_KEY_F6; // 6
  fn_key_map[0b00000111] = HID_KEY_F7; // 7
  fn_key_map[0b00110100] = HID_KEY_F8; // 8
  fn_key_map[0b00110101] = HID_KEY_F9; // 9
  fn_key_map[0b00110110] = HID_KEY_F10; // 0
  fn_key_map[0b00110000] = HID_KEY_F11; // -
  fn_key_map[0b00110001] = HID_KEY_F12; // =
}

void boot_keyboard()
{
#ifdef PPK_DEBUG
  Serial.println("beginning keyboard boot sequence");
#endif

  pinMode(GND_PIN, OUTPUT);
  pinMode(DCD_PIN, INPUT);
  pinMode(RTS_PIN, INPUT);

  digitalWrite(GND_PIN, LOW);

#ifdef PPK_DEBUG
  Serial.print("waiting for DCD_PIN response...");
#endif

  while (digitalRead(DCD_PIN) != HIGH) {
    delay(1);
  };

#ifdef PPK_DEBUG
  Serial.println(" done");
#endif

  Serial1.begin(9600);

#ifdef PPK_DEBUG
  Serial.print("finishing handshake...");
#endif

  if (digitalRead(RTS_PIN) == LOW)
  {
    delay(10);
    pinMode(RTS_PIN, OUTPUT);
    digitalWrite(RTS_PIN, HIGH);
  }
  else
  {
    pinMode(RTS_PIN, OUTPUT);
    digitalWrite(RTS_PIN, HIGH);
    digitalWrite(RTS_PIN, LOW);
    delay(10);
    digitalWrite(RTS_PIN, HIGH);
  }
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

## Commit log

2022-01-17 Adds the source code and 3d model
    [buttons.stl, middle_frame.stl, upper_cap.stl]
2022-01-18 Fix typo about R2
    [blehid_keyboard.ino]
2022-01-19 Fix schematic error.
2022-02-05 Support for Palm V
    [middle_frame.stl, middle_frame_palm_III.stl, middle_frame_palm_V.stl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]
2022-04-26 Added the version 2 code
    [buttons.stl, middle_frame_palm_III.stl, middle_frame_palm_V.stl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]
2022-04-26 Added the version 2 3d print
    [battery_spacer.stl, board_clips.stl, middle_frame_handspring.stl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]
2022-05-05 Fine tune 3d model for version 2
    [board_clips.stl, middle_frame_palm_III.stl, upper_cap.stl]
2022-05-20 Update the wire gauge in the tutorial.
2022-07-20 Update version 2 to work with 3C10317
    [middle_frame_palm_III.stl]
2022-08-09 Update images for new design Palm 3 socket
2022-11-19 change the red LED pin to pin8 to accomodate the new version of LilyGo-T-OI-PLUS board
2023-01-26 Adds explanation about greenand red LED constantly on.
2023-02-16 Fine tune the connector for Palm III
    [middle_frame_palm_III.stl]
2023-08-22 Slightly adjust Palm V micro switch location
    [middle_frame_handspring.stl, middle_frame_palm_III.stl, middle_frame_palm_V.stl]
2024-01-09 Adds support for M500 keyboards
    [middle_frame_palm_III.stl, middle_frame_palm_V.stl, middle_frame_palm_m500.stl]
2024-09-25 add version 3 tutorial
    [board_clips.stl, middle_frame_handspring.stl, middle_frame_palm_III.stl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]
2025-08-08 Adds store links to the PCB
2026-10-30 Add note about glued plastic cap on PCB
    Added a note about the plastic cap being glued to the PCB.
